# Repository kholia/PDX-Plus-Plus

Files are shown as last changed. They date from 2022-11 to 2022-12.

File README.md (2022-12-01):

#### PDX++ (PDX Plus Plus)

A port of https://github.com/WB2CBA/ADX/ to Raspberry Pi Pico with a couple of
enhancements.

PDX++ uses CD2003 (an AM receiver chip) for RX. For TX, we rely on the
AFSK-driving-Si5351 technique. PDX++ uses the common 3 x BS170 Class-E
amplifier design.

Bands covered: 80-meter to 10-meter.

Note: This repository contains the complete source-code for PDX++ (including
KiCad design files).

Update (17-November-2021): PCB V0.01 was sucessfully validated and is on air!

First QSO from PDX++:

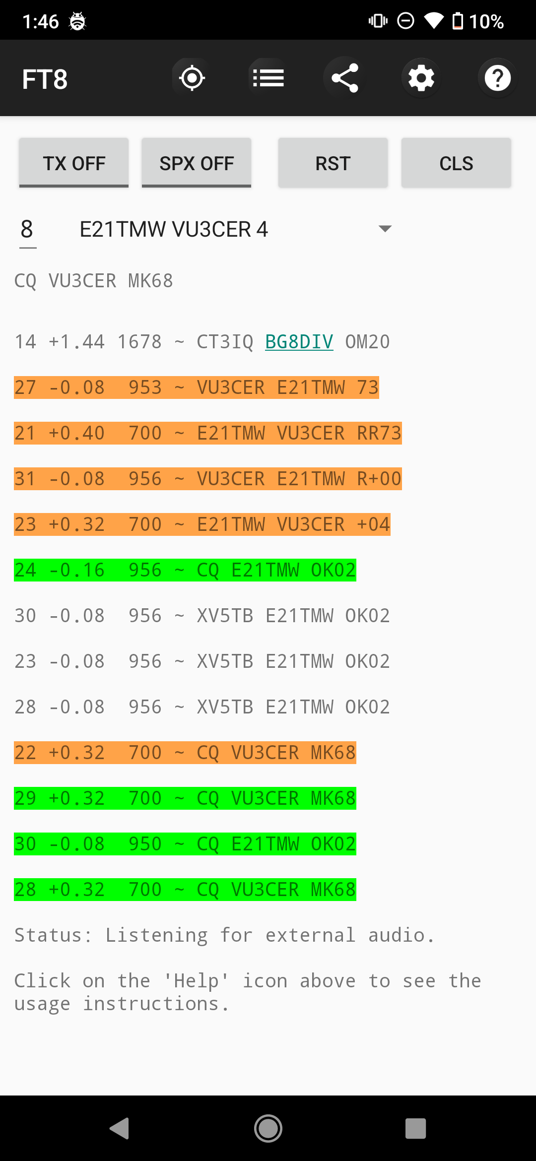
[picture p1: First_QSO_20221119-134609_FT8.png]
First QSO from PDX++ V0.01


QSOs from PDX++:

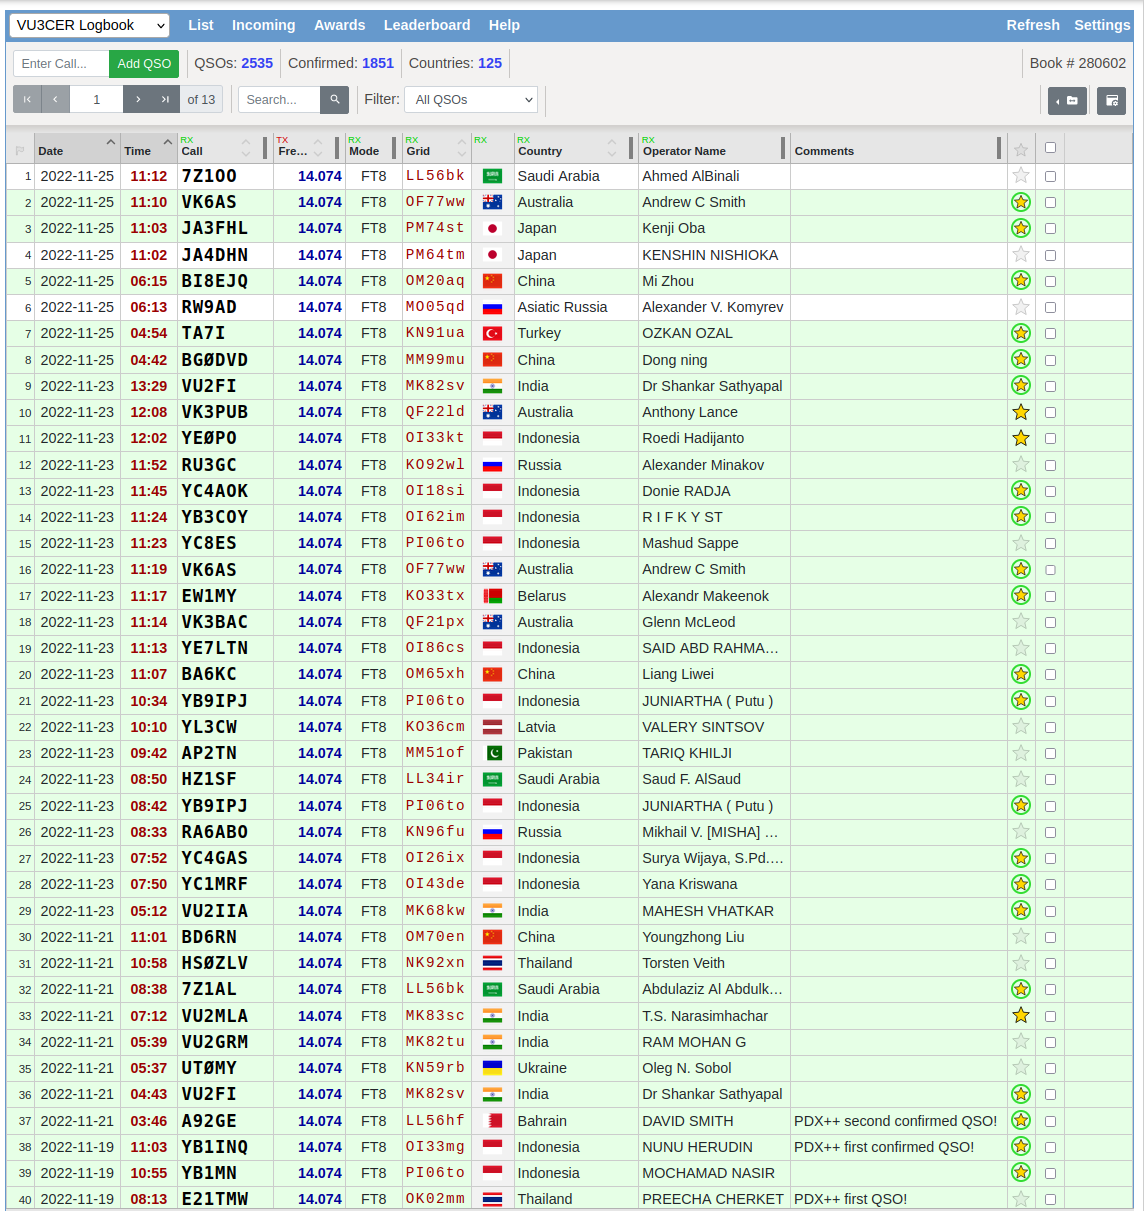
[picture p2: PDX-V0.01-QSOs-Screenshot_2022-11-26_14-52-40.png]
QSOs from PDX++ V0.01


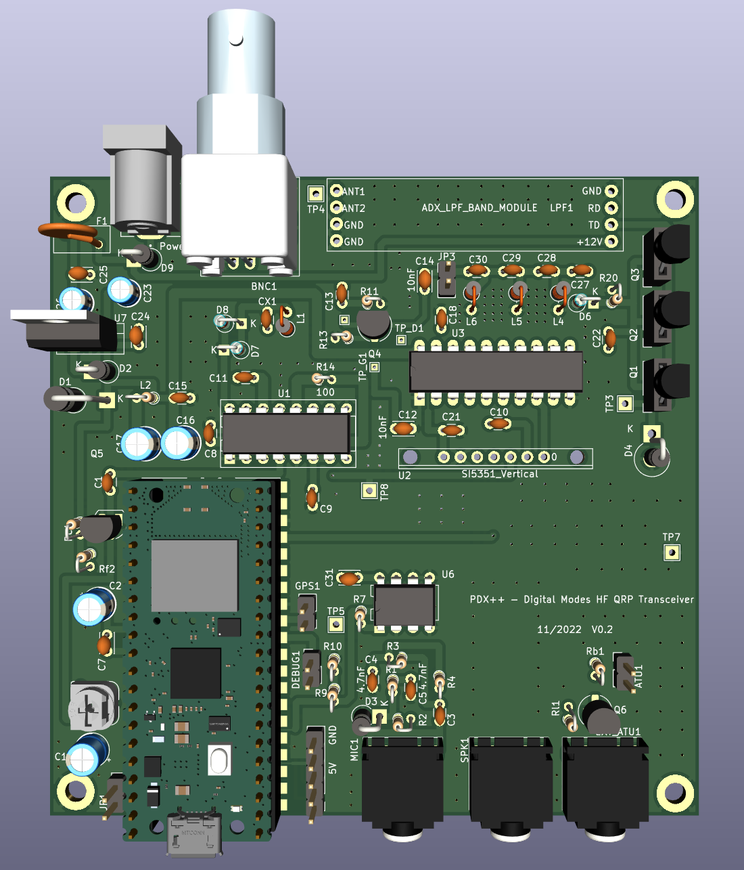
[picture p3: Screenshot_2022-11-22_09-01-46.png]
PCB Render


Note: This project was built using the following:

- KiCad 6.0.x

- https://github.com/earlephilhower/arduino-pico (v2.6.3)

Cost to build: < 1600 INR (around ~20 USD). Including all connectors + LPF.

RX power consumption is 45mA @ 12.0 volts (around 0.56 watt).

#### Schematic

See [the PDX++ schematic](./PDX++.pdf).

#### Build Tips

For the `PCB V0.01` board, build and test the TX section first.

#### Features

- Easy inbuilt and self-sufficient Si5351 calibration

- Inbuilt BCI (broadcast interference) filter

- New AFSK circuit using a LM393 comparator

- Full CAT support (which avoids VOX mode which can trigger false TX under many
  conditions)

- [Optional] Native FT8 decoding on the Pico (via AA1GD)

  - Use https://github.com/kholia/pico_ft8_xcvr firmware

- [Optional] Native spotting (reporting to PSKReporter.info) when using Pico W

  - https://github.com/kholia/SunshineFT8/

#### BOM Sources

International users can buy from Mouser and DigiKey.

Here are some local BOM sources I use:

- https://inkocean.in/ - CD2003 (Chinese clone which is known to work fine)

- https://rarecomponents.com/store/1002 - NXP 1N4148

- https://projectpoint.in/ - CDIL 7805, PJ307 Stereo Socket, winding wire, high quality passives

- https://www.evelta.com/l7805-positive-voltage-regulator-1-5a-5v/ (alternate)

- https://robu.in/product/si5351a-i2c-8-khz-160-mhz-clock-generator-breakout-board-module/

- https://robu.in/product/raspberry-pi-pico/

- https://www.semikart.com/ - has everything we need and more

#### Credits

- https://github.com/WB2CBA/ADX/

- https://github.com/lu7did/ADX-rp2040

- https://github.com/lu7did (ZCD code, freqPIO code)

- https://github.com/aa1gd/pico_ft8_xcvr (AA1GD, for native FT8 decoding)

- https://www.qrz.com/DB/VU2BGS (layout and general help)

#### References

- https://f5npv.wordpress.com/homebrew-ft8qrp-afp-fsk-trx/

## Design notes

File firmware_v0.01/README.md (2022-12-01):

This is the firmware for the `V0.01` PCBs.

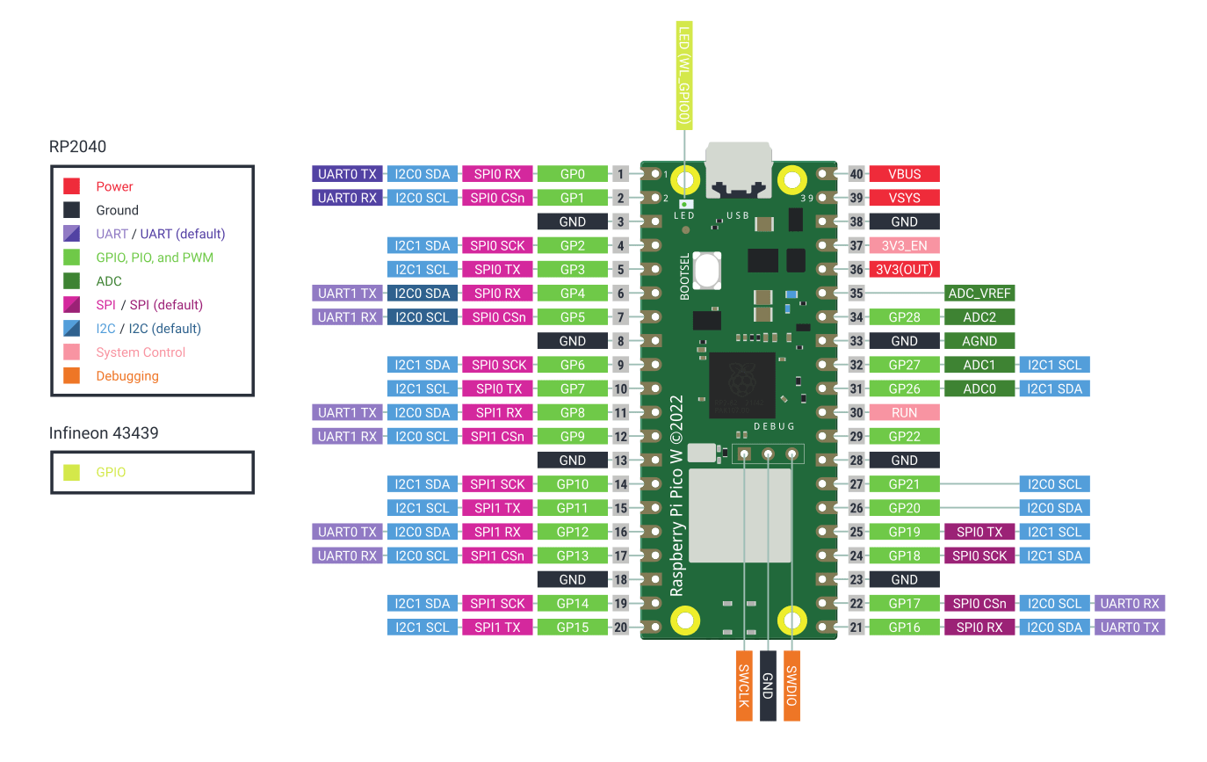
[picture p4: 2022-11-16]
Raspberry-Pi-Pico-W-pinout.png

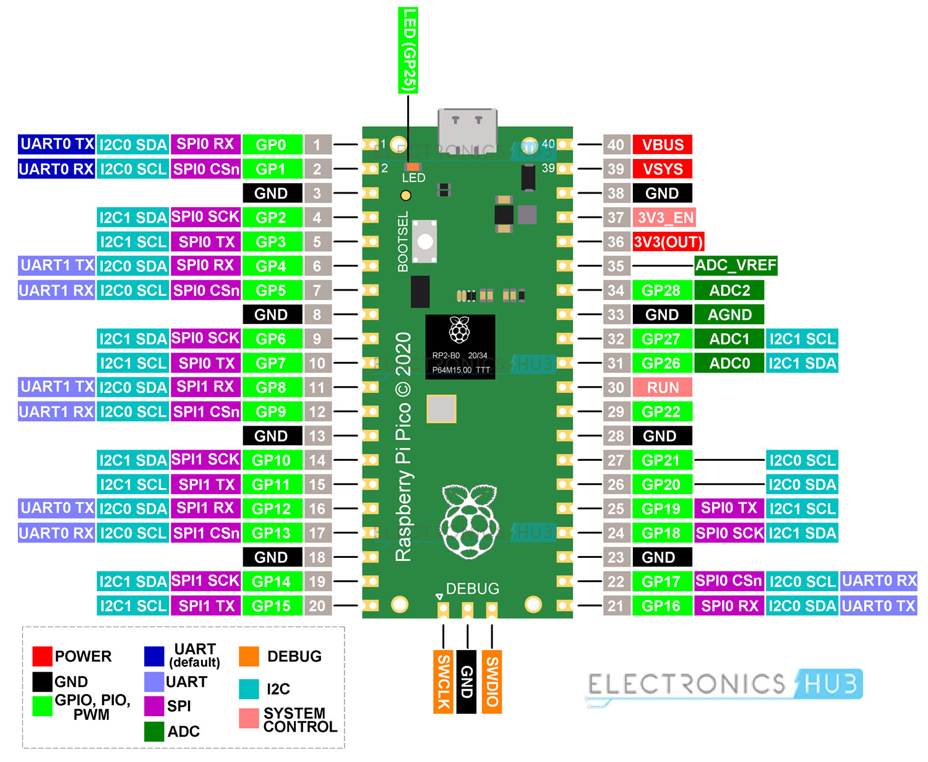
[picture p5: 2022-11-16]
Raspberry-Pi-Pico-Pinout.jpg

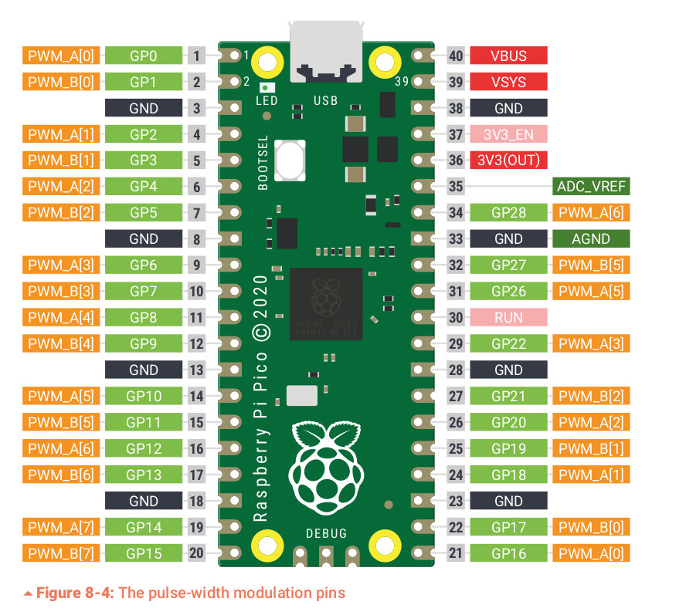
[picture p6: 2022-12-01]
Pico-PWM-Pinout.png

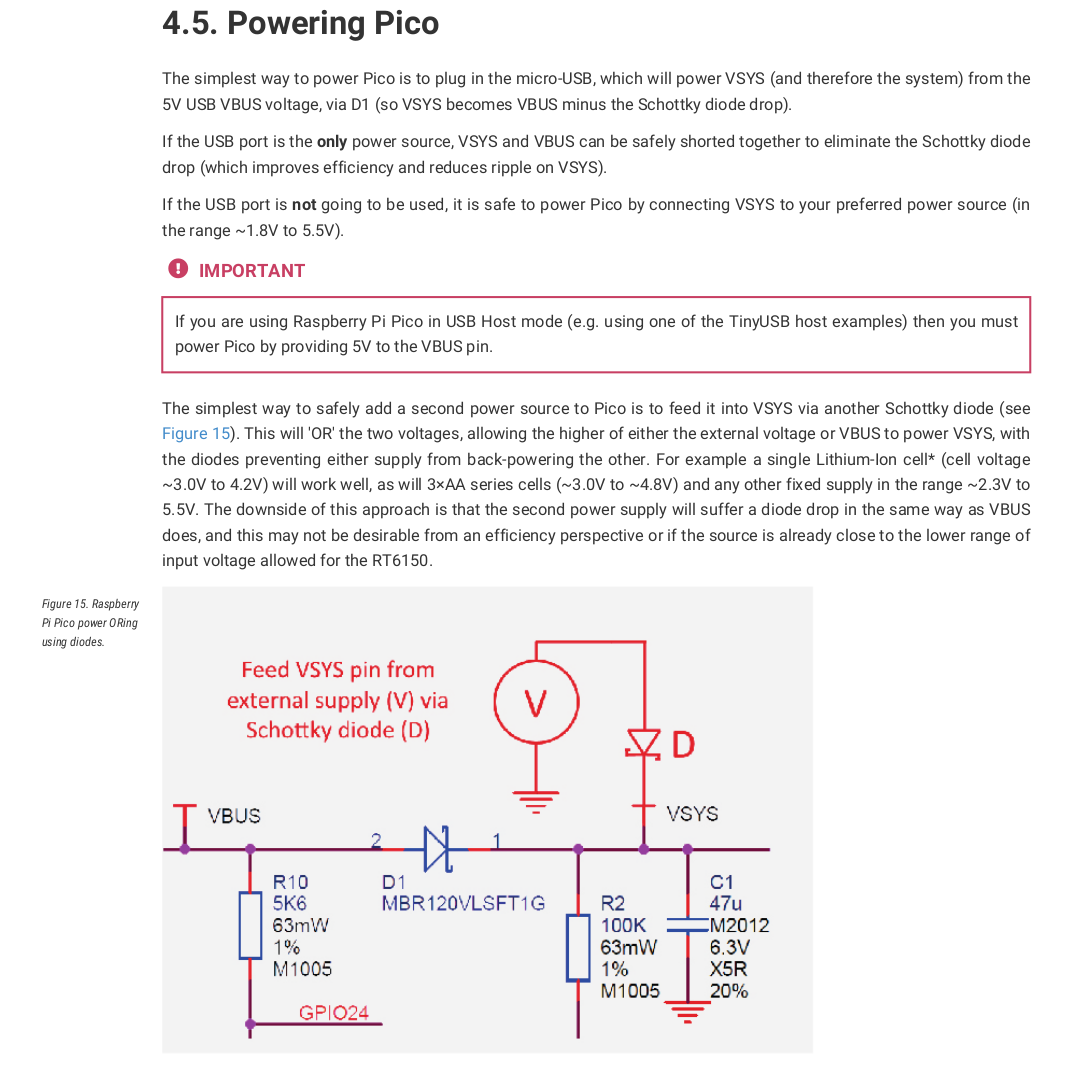
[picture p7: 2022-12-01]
Screenshot_2022-11-25_11-38-42.png

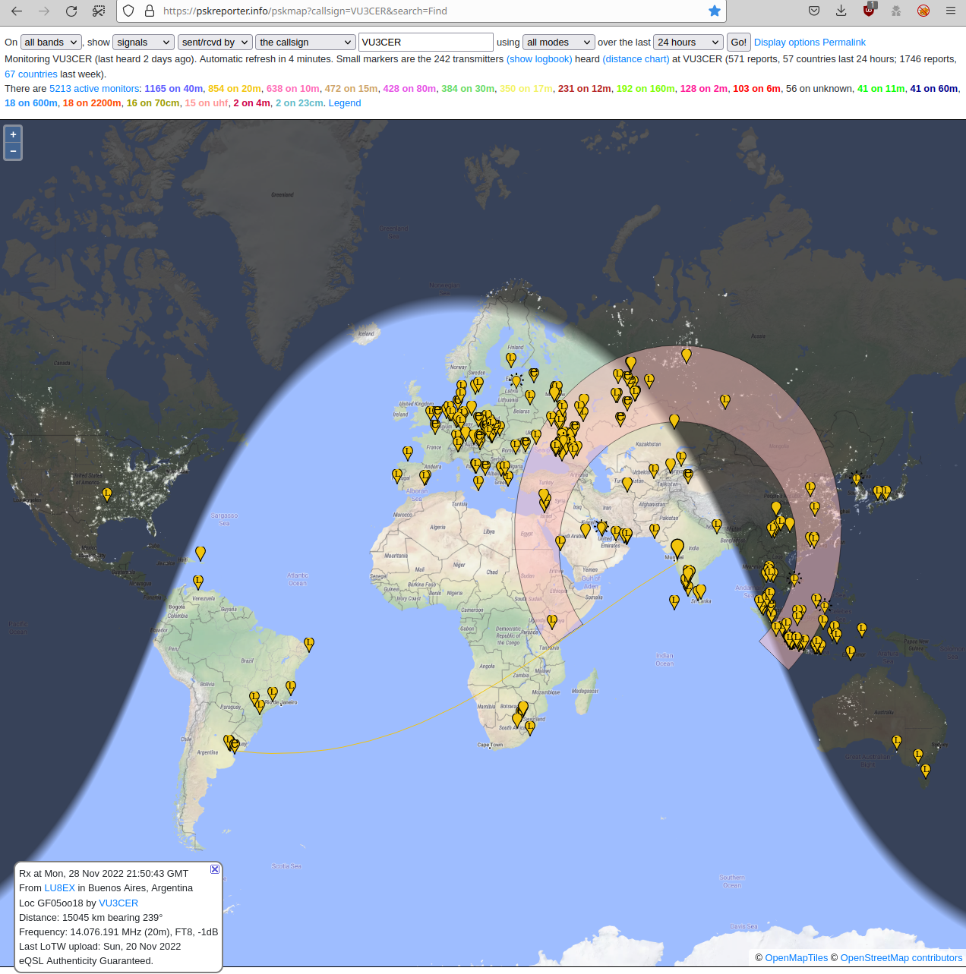
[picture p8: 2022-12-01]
screenshots/Screenshot_2022-11-29_16-37-07.png

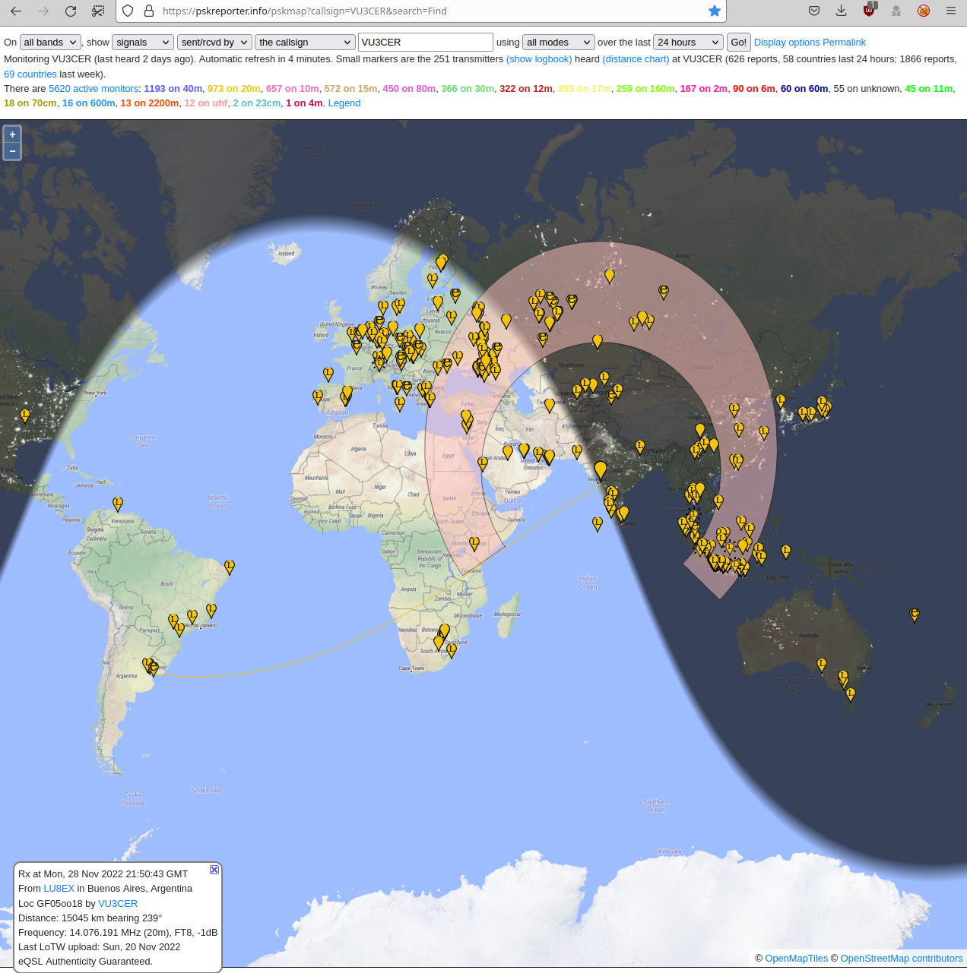
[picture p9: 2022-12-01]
screenshots/Screenshot_2022-11-29_17-54-42.png

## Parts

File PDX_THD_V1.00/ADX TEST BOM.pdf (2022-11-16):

Comment | Designator
SSD1306 | Brd1
100uF/16V | C1,C23,C27
470nF | C12
620pF | C13
Cx | C14
10nF | C19,C20
10uF/16V | C4,C22,C26,C30
10nF | C6,C7
100nF | C2,C3,C5,C8,C9,C10,C11,C15,C16,C17,C18,C21,C24,C25,C28,C29
TX | D1
1N5817 | D10
1N4148 | D2
1N4148 | D4,D5
FT8 | D6
FT4 | D7
JS8 | D8
WSPR | D9
MountingHole_Pad | H1,H2,H3,H4
SMA | J1
BNC | J1A1
PJ‐102A | J2
USB_B | J3
100uH | L1
1uH | L3
100uH | L4,L5,L6
BS170 | Q1,Q2,Q3
BS170 | Q4
1M | R1
2.7k | R10
100 | R11
4.7k | R2
10k | R3,R4,R5,R6
1k | R9,R12,R13,R14,R15,R16
10k | RV1
UP | SW1
BAND | SW2
PA DC | SW3
CLK0 | TP1
CLK1 | TP2
TestPoint | TP3,TP4
| TP5,TP6
GND | TP7
CAL | TP8
CM108AH_Sound_Card | U1
SI535X_Module | U2
74ACT244 | U3
uSDX_LPF_BAND_MODULE | U4
CD2003GB_GP | U5
Arduino_Nano_Socket | XA1

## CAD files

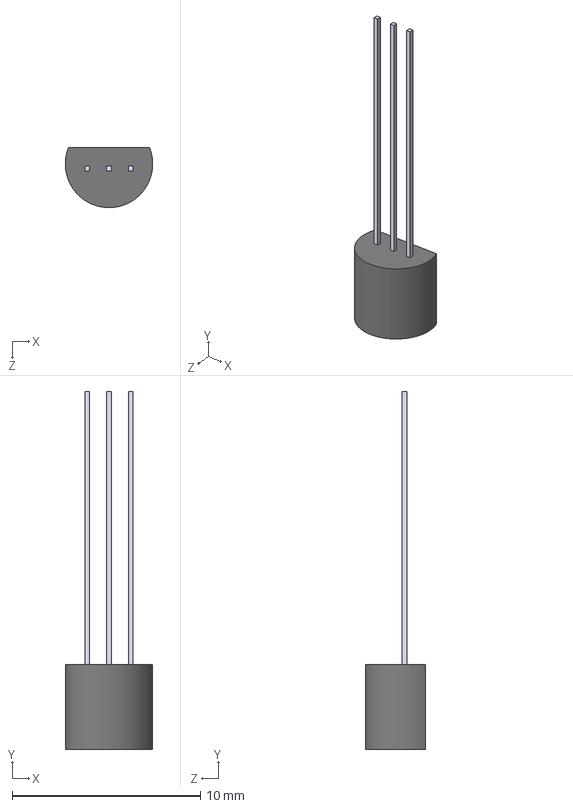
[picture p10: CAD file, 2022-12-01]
models/Transistor_TO-92_Type.STEP
4.64 x 19.0 x 3.20 mm

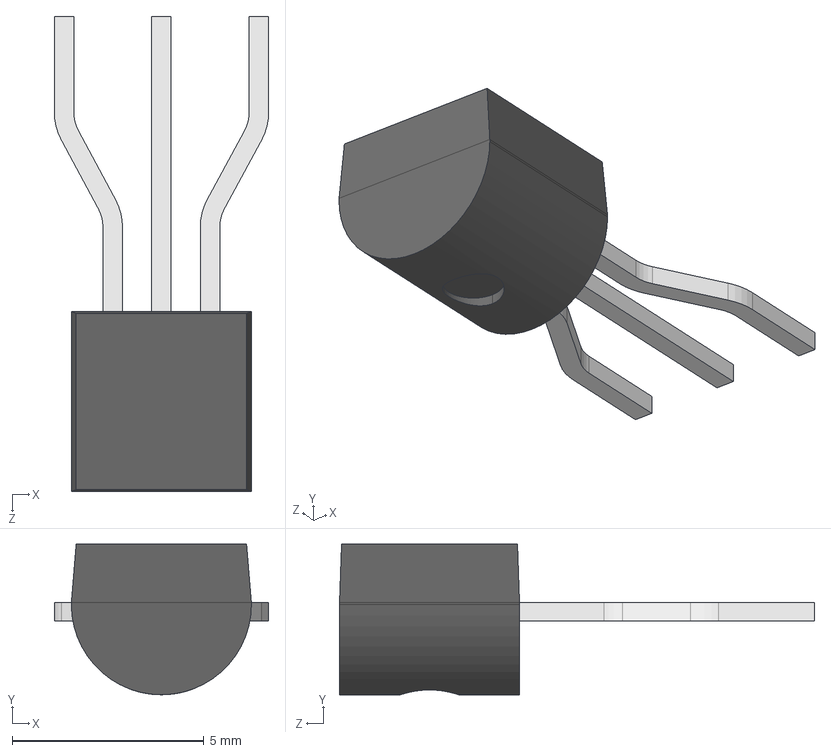
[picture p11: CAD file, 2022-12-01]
models/User Library-TO-92-2_54-line.STEP
5.60 x 3.93 x 12.4 mm
User Library-TO-92 Version2_TO-92 Part1
User Library-TO-92 Version2_TO-92 Part3
User Library-TO-92 Version2_TO-92 Part4
User Library-TO-92 Version2_TO-92 Part5

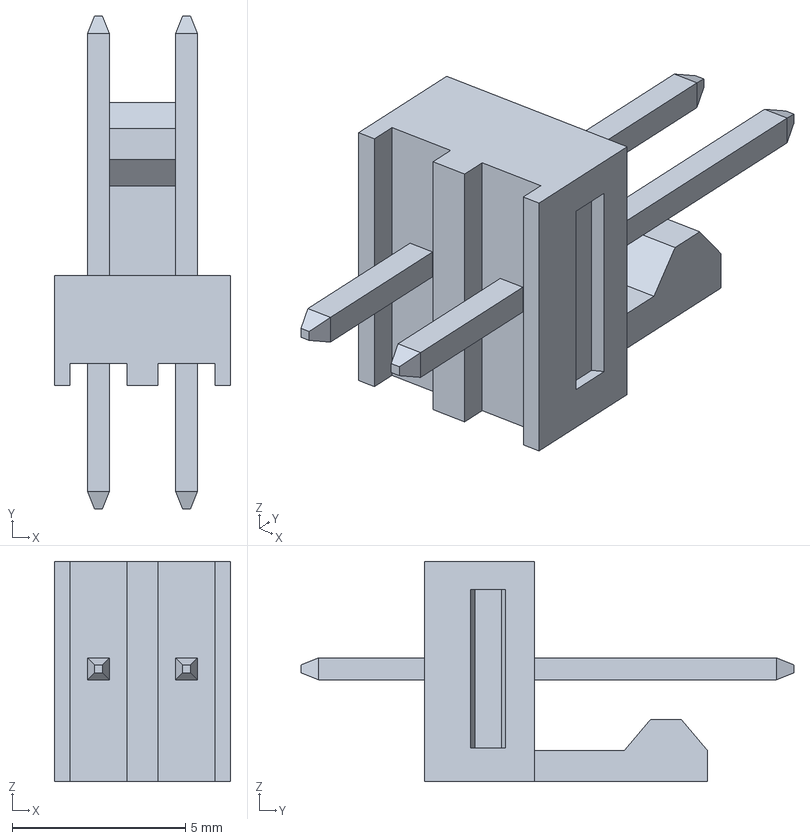
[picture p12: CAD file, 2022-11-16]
models/22-23-2021.stp
5.08 x 14.2 x 6.35 mm

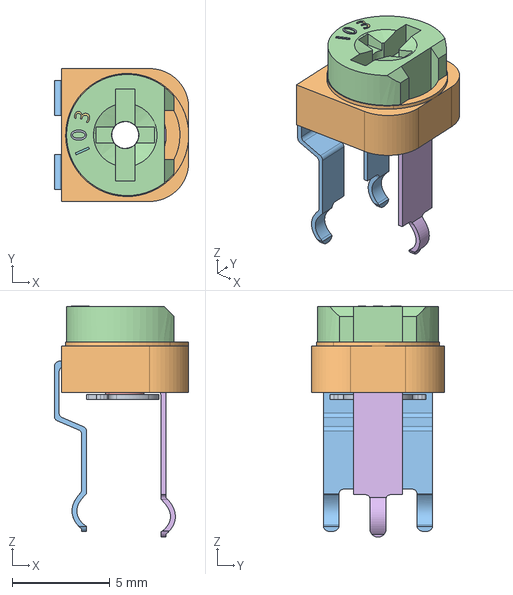
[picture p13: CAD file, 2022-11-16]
models/Poti_10kohm.stp
6.88 x 6.80 x 11.8 mm

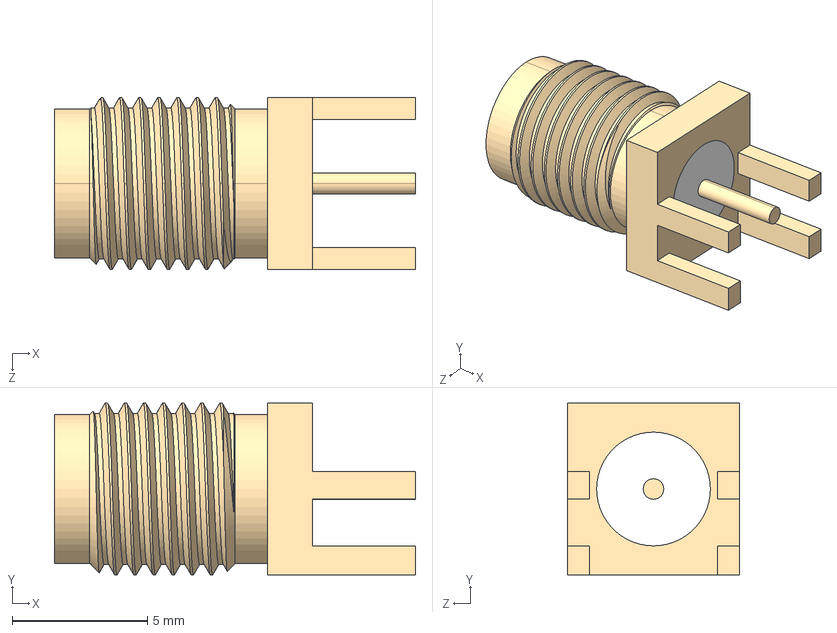
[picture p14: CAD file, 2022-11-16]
models/CON-SMA-EDGE-S--3DModel-STEP-56544.STEP
13.3 x 6.35 x 6.35 mm

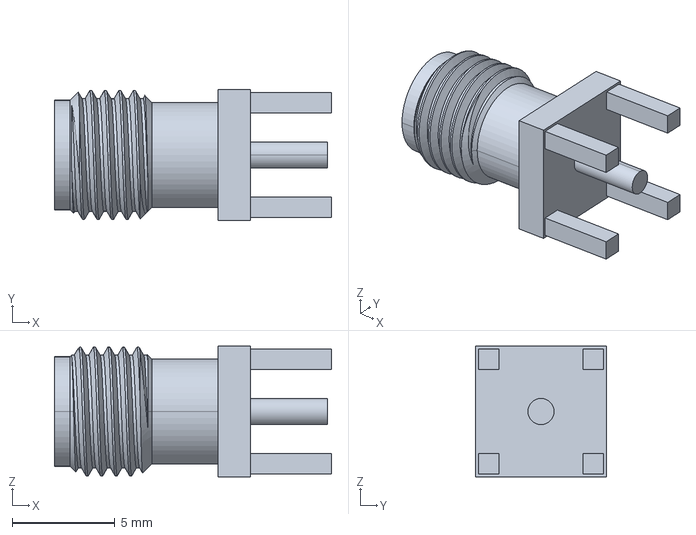
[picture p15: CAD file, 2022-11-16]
models/901-144.stp
13.5 x 6.35 x 6.35 mm

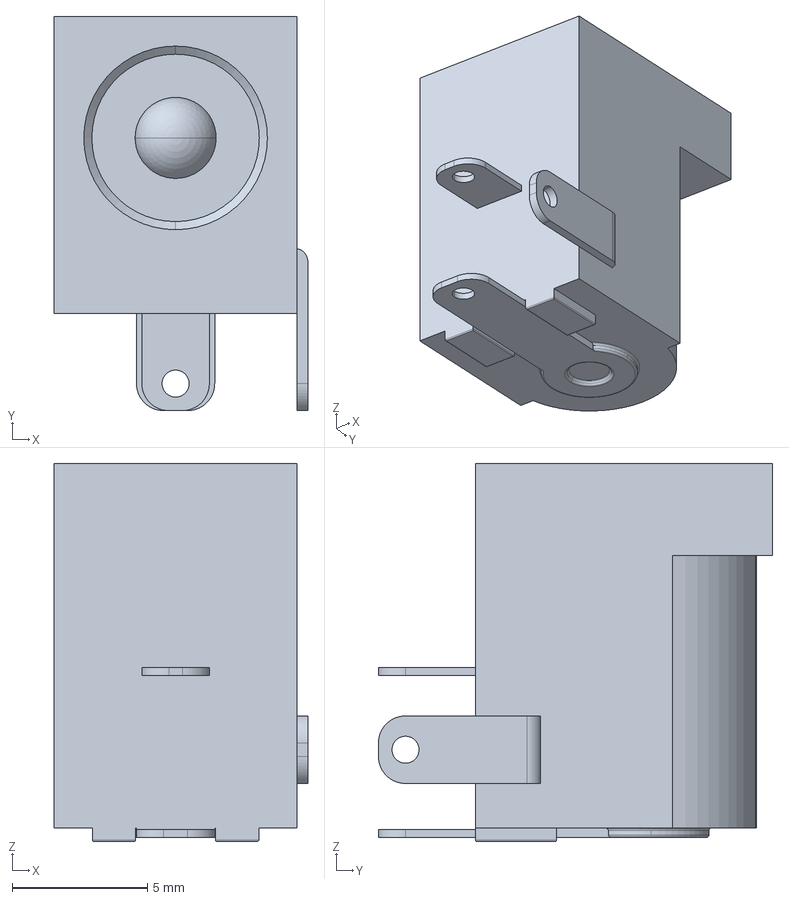
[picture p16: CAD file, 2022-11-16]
models/DC-005-5A-2.0.step
9.40 x 14.6 x 14.0 mm

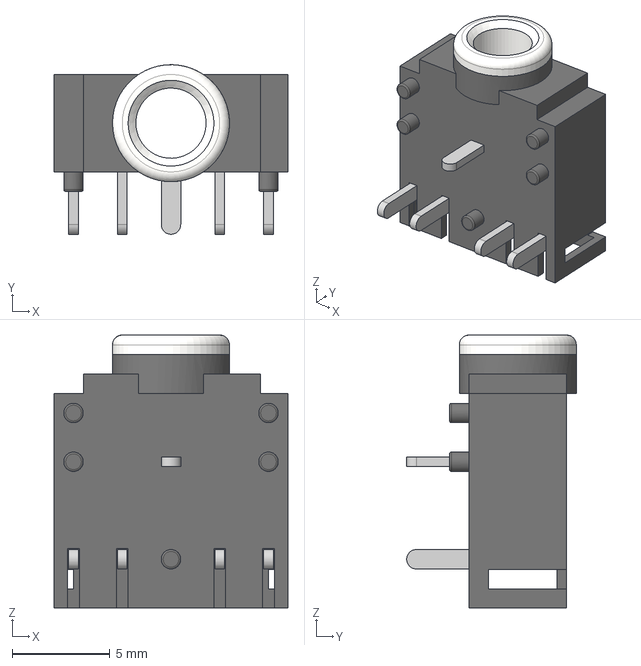
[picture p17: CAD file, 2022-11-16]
models/pj-307.step
12.0 x 8.70 x 14.0 mm

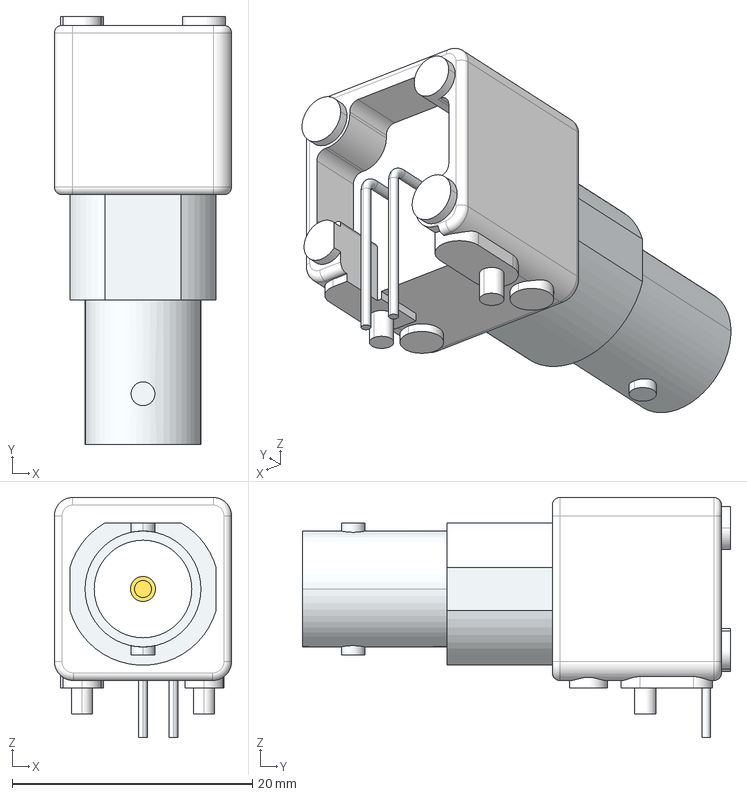
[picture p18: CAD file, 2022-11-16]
models/1564889-62.stp
14.8 x 35.7 x 20.0 mm

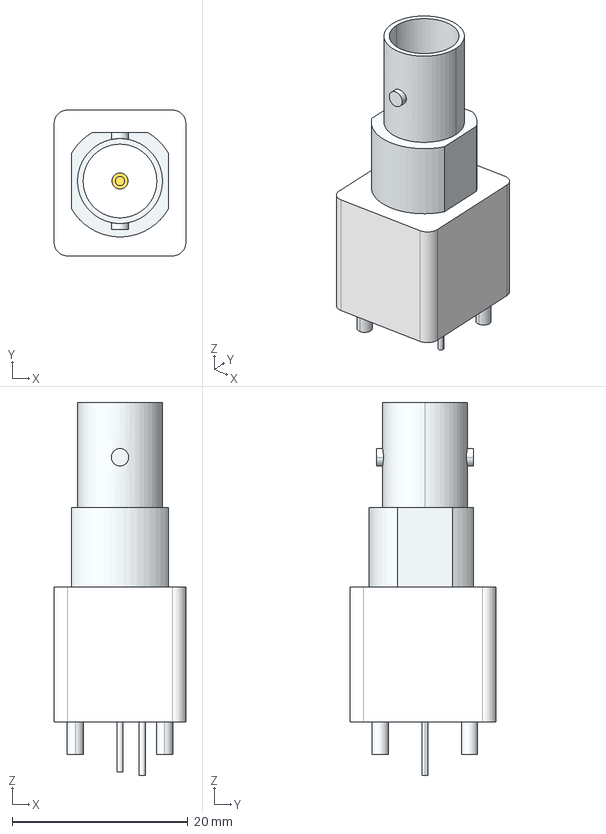
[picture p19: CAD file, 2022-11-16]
models/1566143-62.stp
15.0 x 16.6 x 42.4 mm

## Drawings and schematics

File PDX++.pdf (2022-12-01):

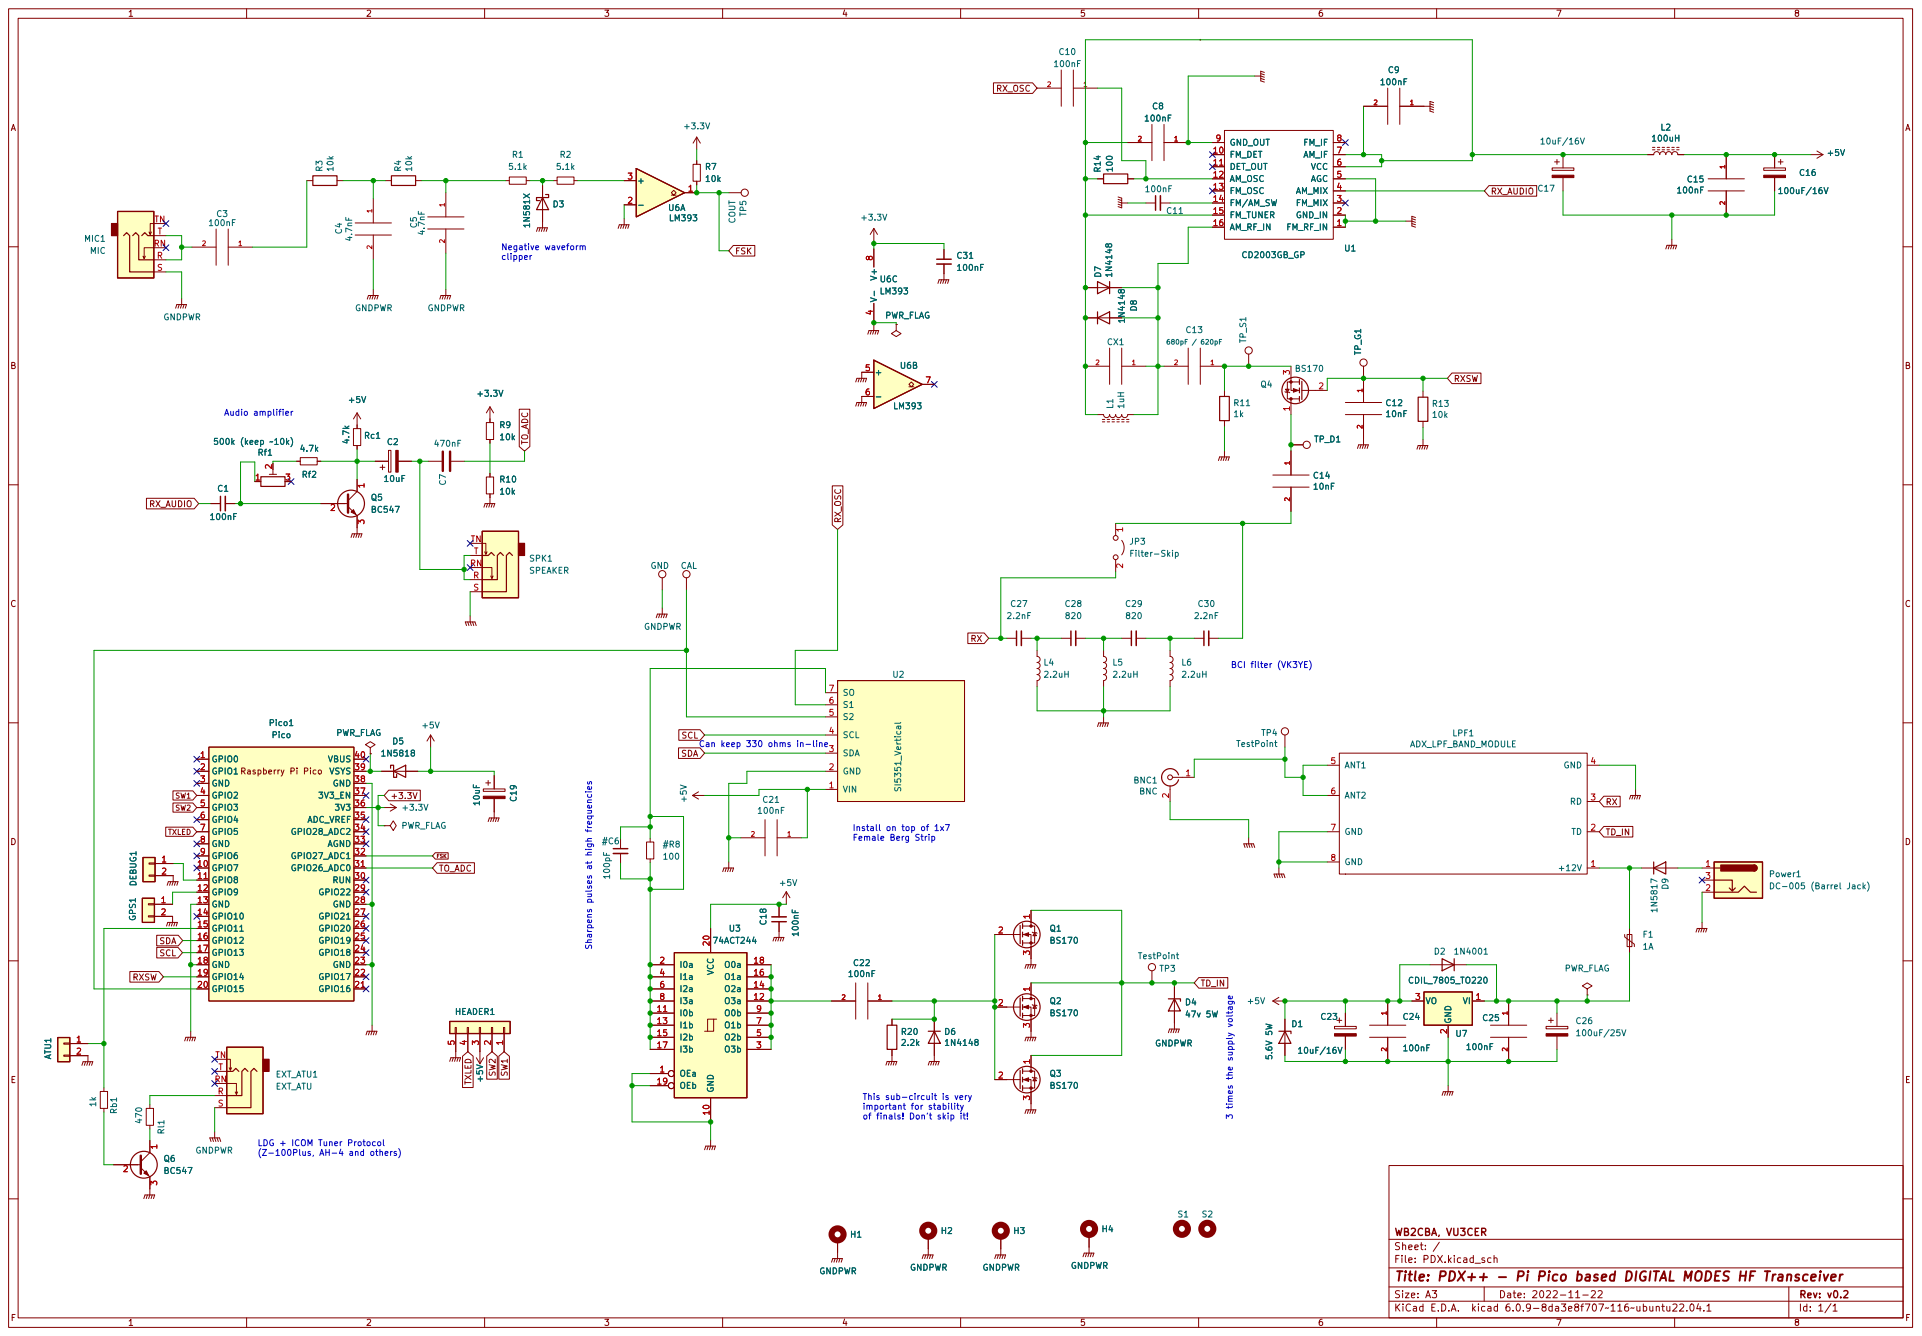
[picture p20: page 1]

3 Pico1 Pico GPIO0 1 GPIO7 10 GPIO8 11 GPIO9 12 GND 13 GPIO10 14 GPIO11 15 GPIO12 16 GPIO13 17 GND 18 GPIO14 19 GPIO1 2 GPIO15 20 GPIO16 21 GPIO17 22 GND 23 GPIO18 24 GPIO19 25 GPIO20 26 GPIO21 27 GND 28 GPIO22 29 GND 3 RUN 30 GPIO26_ADC0 31 GPIO27_ADC1 32 AGND 33 GPIO28_ADC2 34 ADC_VREF 35

Can keep 330 ohms in-line
SDA

Install on top of 1x7
Female Berg Strip

This sub-circuit is very
important for stability

of finals! Don't skip it! LDG + ICOM Tuner Protocol (Z-100Plus, AH-4 and others)

Id: 1/1 Title: PDX++ - Pi Pico based DIGITAL MODES HF Transceiver

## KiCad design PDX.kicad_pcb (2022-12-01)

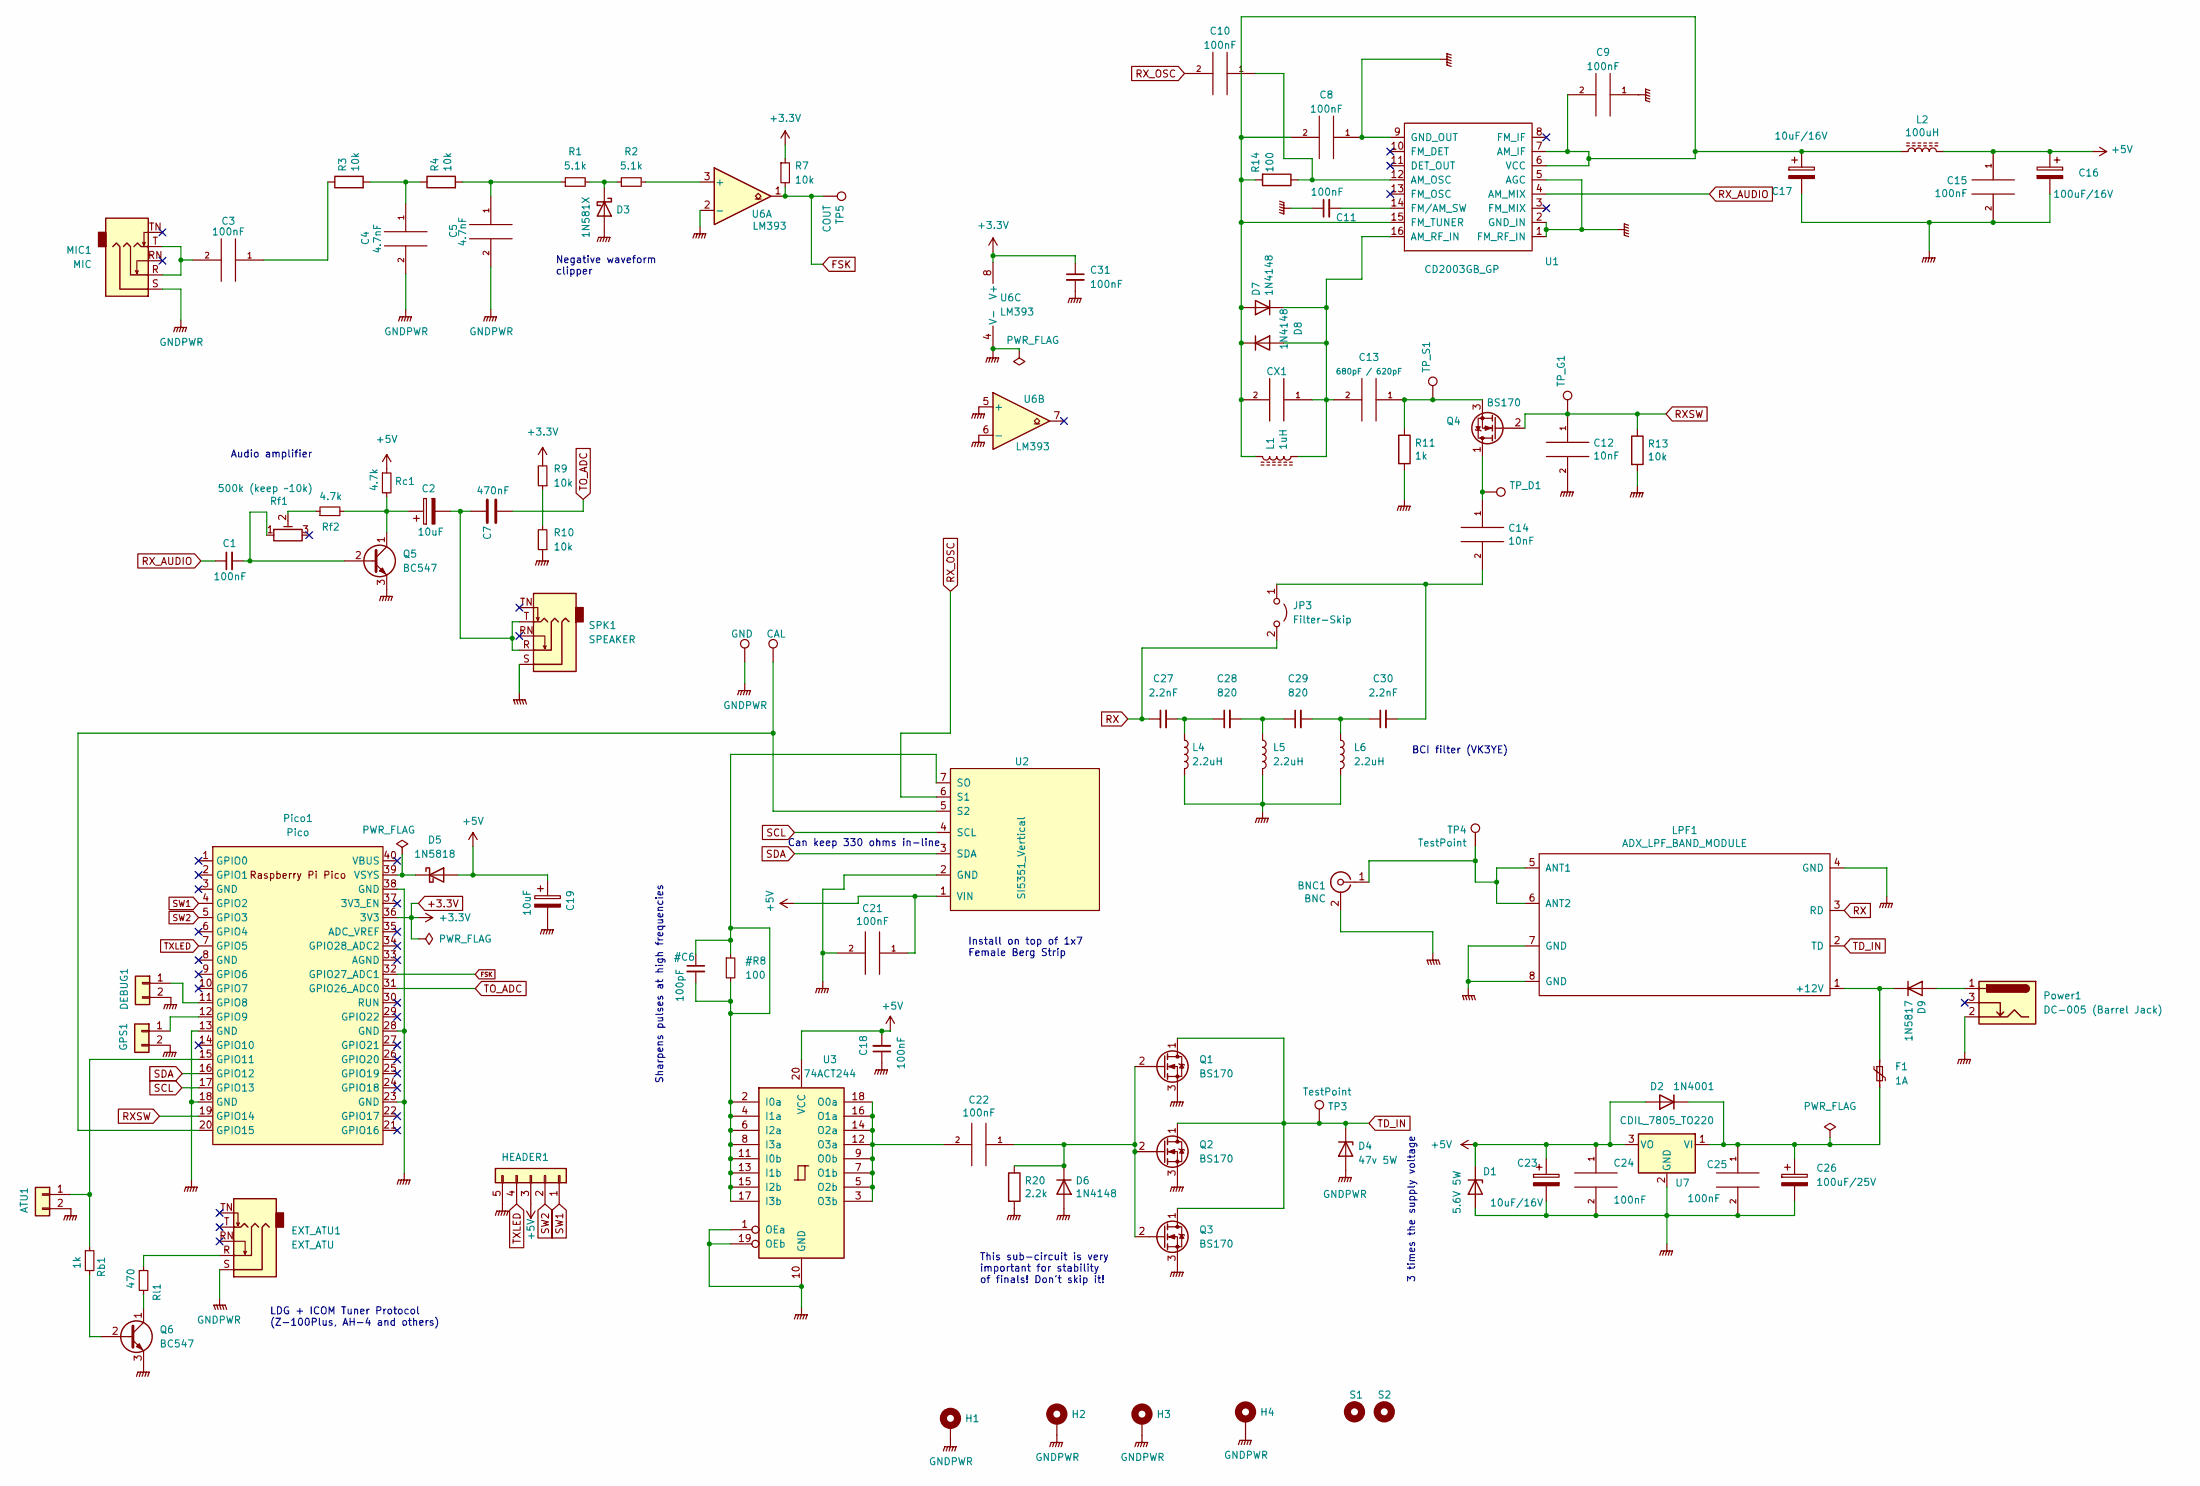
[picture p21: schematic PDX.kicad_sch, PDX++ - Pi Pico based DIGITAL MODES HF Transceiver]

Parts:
ATU1: Conn_01x02; PinHeader_1x02_P2.54mm_Vertical
BNC1: BNC; BNC_Amphenol_B6252HB-NPP3G-50_Horizontal
C1, C3, C8, C9, C10, C11, C15, C18, C21, C22: 100nF; C_Disc_D3.0mm_W1.6mm_P2.50mm
C2, C19: 10uF; CP_Radial_D5.0mm_P2.50mm
C4, C5: 4.7nF; C_Disc_D3.0mm_W1.6mm_P2.50mm
C7: 470nF; C_Disc_D3.0mm_W2.0mm_P2.50mm
C12, C14: 10nF; C_Disc_D3.0mm_W2.0mm_P2.50mm
C13: 680pF / 620pF; C_Disc_D3.0mm_W1.6mm_P2.50mm
C16: 100uF/16V; CP_Radial_D5.0mm_P2.50mm
C17: 10uF/16V; CP_Radial_D5.0mm_P2.50mm
C23: 10uF/16V; CP_Radial_D4.0mm_P2.00mm
C24, C25, C31: 100nF; C_Disc_D3.0mm_W2.0mm_P2.50mm
C26: 100uF/25V; CP_Radial_D4.0mm_P2.00mm
C27, C30: 2.2nF; C_Disc_D3.0mm_W1.6mm_P2.50mm
C28, C29: 820; C_Disc_D3.0mm_W1.6mm_P2.50mm
CX1: C_Disc_D3.0mm_W1.6mm_P2.50mm
D1: 5.6V 5W; D_DO-15_P5.08mm_Vertical_KathodeUp
D2: 1N4001; D_DO-41_SOD81_P2.54mm_Vertical_KathodeUp
D3: 1N581X; D_DO-41_SOD81_P2.54mm_Vertical_KathodeUp
D4: 47v 5W; D_DO-201_P3.81mm_Vertical_KathodeUp
D5: 1N5818; D_DO-41_SOD81_P2.54mm_Vertical_KathodeUp
D6, D7, D8: 1N4148; D_DO-35_SOD27_P2.54mm_Vertical_KathodeUp
D9: 1N5817; D_DO-41_SOD81_P2.54mm_Vertical_KathodeUp
DEBUG1: Conn_01x02; PinHeader_1x02_P2.54mm_Vertical
EXT_ATU1: EXT_ATU; PJ-307_Modded
F1: 1A; Fuse_BelFuse_0ZRE0005FF_L8.3mm_W3.8mm
GPS1: Conn_01x02; PinHeader_1x02_P2.54mm_Vertical
H1, H2, H3, H4: MountingHole_Pad; MountingHole_3.2mm_M3_ISO7380_Pad
HEADER1: Conn_01x05; PinHeader_1x05_P2.54mm_Vertical
JP3: Filter-Skip; PinHeader_1x02_P2.54mm_Vertical
L1: 1uH; L_Axial_L5.3mm_D2.2mm_P2.54mm_Vertical_Vishay_IM-1
L2: 100uH; R_Axial_DIN0204_L3.6mm_D1.6mm_P2.54mm_Vertical
L4, L5, L6: 2.2uH; L_Axial_L5.3mm_D2.2mm_P2.54mm_Vertical_Vishay_IM-1
LPF1: ADX_LPF_BAND_MODULE; uSDX_LPF_Band_Module
MIC1: MIC; PJ-307_Modded
Pico1: Pico; RPi_Pico_SMD_TH
Power1: DC-005 (Barrel Jack); XKB_DC-005-5A-2.0
Q1, Q2, Q3: BS170; PinSocket_1x03_P2.54mm_Vertical
Q4: BS170; TO-92_HandSolder
Q5, Q6: BC547; TO-92_HandSolder
R1, R2: 5.1k; R_Axial_DIN0204_L3.6mm_D1.6mm_P1.90mm_Vertical
R3, R4, R7, R9, R10, R13: 10k; R_Axial_DIN0204_L3.6mm_D1.6mm_P1.90mm_Vertical
R11: 1k; R_Axial_DIN0204_L3.6mm_D1.6mm_P1.90mm_Vertical
R14: 100; R_Axial_DIN0204_L3.6mm_D1.6mm_P1.90mm_Vertical
R20: 2.2k; R_Axial_DIN0204_L3.6mm_D1.6mm_P1.90mm_Vertical
Rb1: 1k; R_Axial_DIN0204_L3.6mm_D1.6mm_P1.90mm_Vertical
Rc1: 4.7k; R_Axial_DIN0204_L3.6mm_D1.6mm_P1.90mm_Vertical
Rf1: 500k (keep ~10k); Potentiometer_Runtron_RM-065_Vertical
Rf2: 4.7k; R_Axial_DIN0204_L3.6mm_D1.6mm_P1.90mm_Vertical
Rl1: 470; R_Axial_DIN0204_L3.6mm_D1.6mm_P1.90mm_Vertical
S1, S2: MountingHole; MountingHole_2.2mm_M2
SPK1: SPEAKER; PJ-307_Modded
TP3, TP4: TestPoint; TestPoint_THTPad_2.0x2.0mm_Drill1.0mm
TP5: COUT; TestPoint_THTPad_2.0x2.0mm_Drill1.0mm
TP7: GND; TestPoint_THTPad_2.0x2.0mm_Drill1.0mm
TP8: CAL; TestPoint_THTPad_2.0x2.0mm_Drill1.0mm
TP_D1: TestPoint_THTPad_1.0x1.0mm_Drill0.5mm
TP_G1: TestPoint_THTPad_1.0x1.0mm_Drill0.5mm
TP_S1: TestPoint_THTPad_1.0x1.0mm_Drill0.5mm
U1: CD2003GB_GP; DIP-16_W7.62mm_Socket
U2: SI5351_Vertical; SI5351 Module_Vertical
U3: 74ACT244; DIP-20_W7.62mm_LongPads
U6: LM393; DIP-8_W7.62mm
U7: CDIL_7805_TO220; TO-220-3_Vertical

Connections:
+3.3V: C31.1, Pico1.36 (3V3), R7.1, R9.2, U6.8 (V+)
+5V: C15.1, C16.1, C18.2, C19.1, C21.1, C23.1, C24.1, D1.1 (K), D2.2 (A), D5.2 (A), HEADER1.3, L2.1, Rc1.1, U2.1 (VIN), U3.20 (VCC), U7.3 (VO)
FSK: Pico1.32 (GPIO27_ADC1), R7.2, TP5.1, U6.1
GNDPWR: ATU1.2, BNC1.2 (Ext), C4.2, C5.2, C8.1, C9.1, C11.1, C12.2, C15.2, C16.2, C17.2, C18.1, C19.2, C21.2, C23.2, C24.2, C25.2, C26.2, C31.2, D1.2 (A), D3.2 (A), D4.2 (A), D6.2 (A), DEBUG1.2, EXT_ATU1.S, GPS1.2, H1.1, H2.1, H3.1, H4.1, HEADER1.5, L4.2, L5.2, L6.2, LPF1.4 (GND), LPF1.7 (GND), LPF1.8 (GND), MIC1.S, Pico1.13 (GND), Pico1.18 (GND), Pico1.23 (GND), Pico1.28 (GND), Pico1.38 (GND), Power1.2, Q1.3 (S), Q2.3 (S), Q3.3 (S), Q5.3 (E), Q6.3 (E), R10.1, R11.2, R13.2, R20.2, SPK1.S, TP7.1, U1.1 (FM_RF_IN), U1.2 (GND_IN), U1.5 (AGC), U1.9 (GND_OUT), U2.2 (GND), U3.1 (OEa), U3.10 (GND), U3.19 (OEb), U6.2 (-), U6.4 (V-), U6.5 (+), U6.6 (-), U7.2 (GND)
unnamed: ATU1.1, Pico1.15 (GPIO11), Rb1.1
unnamed: BNC1.1 (In), LPF1.5 (ANT1), LPF1.6 (ANT2), TP4.1
unnamed: C1.2, Q5.2 (B), Rf1.1
unnamed: C2.1, Q5.1 (C), Rc1.2, Rf2.2
unnamed: C2.2, C7.2, SPK1.R, SPK1.T
unnamed: C3.1, R3.1
unnamed: C3.2, MIC1.R, MIC1.T
unnamed: C4.1, R3.2, R4.1
unnamed: C5.1, R1.1, R4.2
unnamed: C10.1, R14.1, U1.12 (AM_OSC)
unnamed: C11.2, U1.14 (FM/AM_SW)
unnamed: C13.1, Q4.3 (S), R11.1, TP_S1.1
unnamed: C13.2, CX1.1, D7.1 (K), D8.2 (A), L1.1, U1.16 (AM_RF_IN)
unnamed: C14.1, Q4.1 (D), TP_D1.1
unnamed: C14.2, C30.2, JP3.1 (A)
unnamed: C8.2, C9.2, C17.1, CX1.2, D7.2 (A), D8.1 (K), L1.2, L2.2, R14.2, U1.6 (VCC), U1.7 (AM_IF), U1.15 (FM_TUNER)
unnamed: C22.1, D6.1 (K), Q1.2 (G), Q2.2 (G), Q3.2 (G), R20.1
unnamed: C22.2, U3.3 (O3b), U3.5 (O2b), U3.7 (O1b), U3.9 (O0b), U3.12 (O3a), U3.14 (O2a), U3.16 (O1a), U3.18 (O0a)
unnamed: C25.1, C26.1, D2.1 (K), F1.2, U7.1 (VI)
unnamed: C27.2, C28.1, L4.1
unnamed: C28.2, C29.1, L5.1
unnamed: C29.2, C30.1, L6.1
unnamed: D3.1 (K), R1.2, R2.1
unnamed: D5.1 (K), Pico1.39 (VSYS)
unnamed: D9.1 (K), F1.1, LPF1.1 (+12V)
unnamed: D9.2 (A), Power1.1
unnamed: DEBUG1.1, Pico1.11 (GPIO8)
unnamed: EXT_ATU1.R, Rl1.1
unnamed: GPS1.1, Pico1.12 (GPIO9)
unnamed: Pico1.20 (GPIO15), TP8.1, U2.5 (S2)
unnamed: Q6.1 (C), Rl1.2
unnamed: Q6.2 (B), Rb1.2
unnamed: R2.2, U6.3 (+)
unnamed: R9.1, R10.2
unnamed: Rf1.2, Rf2.1
unnamed: U2.7 (SO), U3.2 (I0a), U3.4 (I1a), U3.6 (I2a), U3.8 (I3a), U3.11 (I0b), U3.13 (I1b), U3.15 (I2b), U3.17 (I3b)
RX: C27.1, JP3.2 (B), LPF1.3 (RD)
RXSW: C12.1, Pico1.19 (GPIO14), Q4.2 (G), R13.1, TP_G1.1
RX_AUDIO: C1.1, U1.4 (AM_MIX)
RX_OSC: C10.2, U2.6 (S1)
SCL: Pico1.17 (GPIO13), U2.4 (SCL)
SDA: Pico1.16 (GPIO12), U2.3 (SDA)
SW1: HEADER1.1, Pico1.4 (GPIO2)
SW2: HEADER1.2, Pico1.5 (GPIO3)
TD_IN: D4.1 (K), LPF1.2 (TD), Q1.1 (D), Q2.1 (D), Q3.1 (D), TP3.1
TO_ADC: C7.1, Pico1.31 (GPIO26_ADC0)
TXLED: HEADER1.4, Pico1.7 (GPIO5)

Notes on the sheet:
Install on top of 1x7 Female Berg Strip
This sub-circuit is very important for stability of finals! Don't skip it!
Audio amplifier
Can keep 330 ohms in-line
Sharpens pulses at high frequencies
Negative waveform clipper
LDG + ICOM Tuner Protocol (Z-100Plus, AH-4 and others)
BCI filter (VK3YE)
3 times the supply voltage

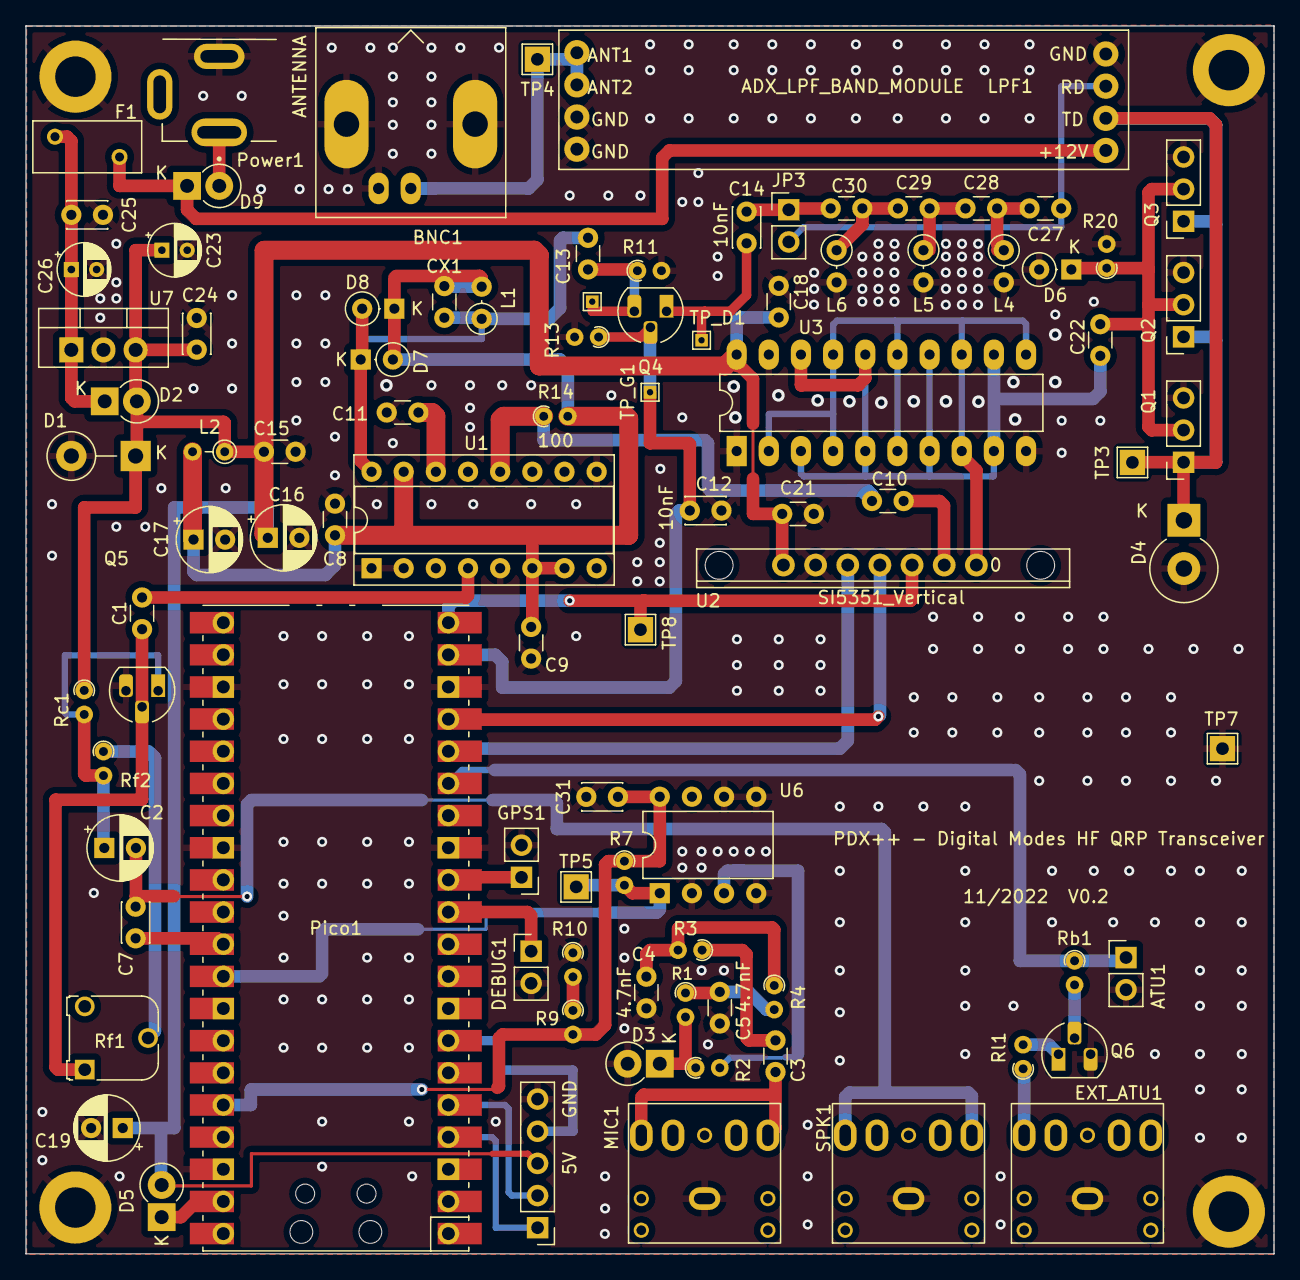
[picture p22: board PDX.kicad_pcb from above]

Board: 2 copper layers, 98.6 x 97.0 mm, 98 parts (0 on the bottom side), 51 nets.

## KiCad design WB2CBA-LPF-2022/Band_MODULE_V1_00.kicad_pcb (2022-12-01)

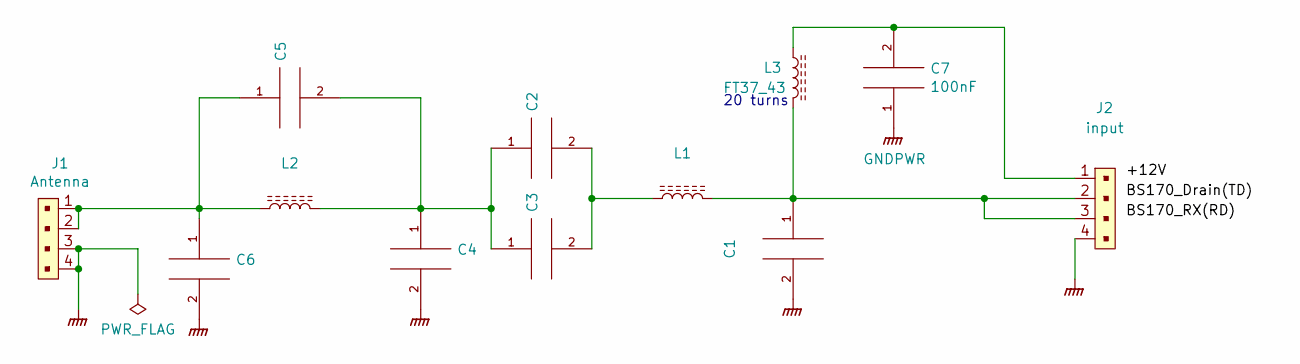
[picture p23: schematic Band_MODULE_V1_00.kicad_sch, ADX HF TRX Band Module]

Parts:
C1, C2, C3, C4, C5, C6: C_Disc_D5.0mm_W2.5mm_P2.50mm
C7: 100nF; C_Disc_D5.0mm_W2.5mm_P2.50mm
J1: Antenna; PinHeader_1x4_P2.54mm_Drill1.02mm; MPN 0022232041; Digi-Key_PN WM4202-ND
J2: input; PinHeader_1x4_P2.54mm_Drill1.02mm; MPN 0022232041; Digi-Key_PN WM4202-ND
L1, L2: L_Toroid_Vertical_L10.0mm_W5.0mm_P5.08mm
L3: FT37_43; L_Toroid_Vertical_L10.0mm_W5.0mm_P5.08mm

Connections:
GNDPWR: C1.2, C4.2, C6.2, C7.1, J1.3, J1.4, J2.4
unnamed: C1.1, J2.2, J2.3, L1.2, L3.2
unnamed: C2.1, C3.1, C4.1, C5.2, L2.2
unnamed: C2.2, C3.2, L1.1
unnamed: C5.1, C6.1, J1.1, J1.2, L2.1
unnamed: C7.2, J2.1, L3.1

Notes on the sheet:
20 turns

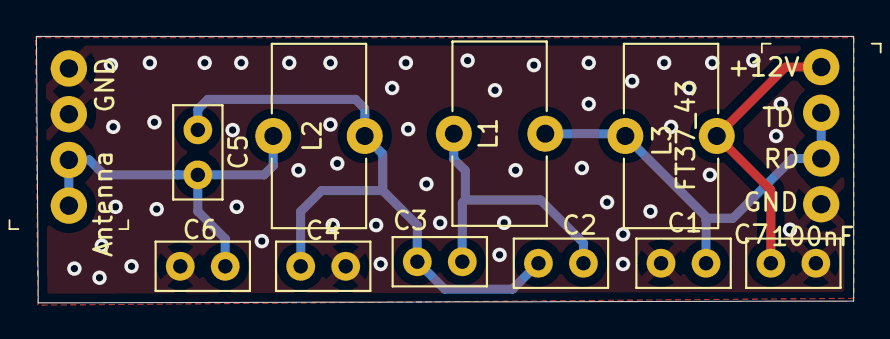
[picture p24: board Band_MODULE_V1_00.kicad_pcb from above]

Board: 2 copper layers, 45.4 x 14.8 mm, 12 parts (0 on the bottom side), 6 nets.

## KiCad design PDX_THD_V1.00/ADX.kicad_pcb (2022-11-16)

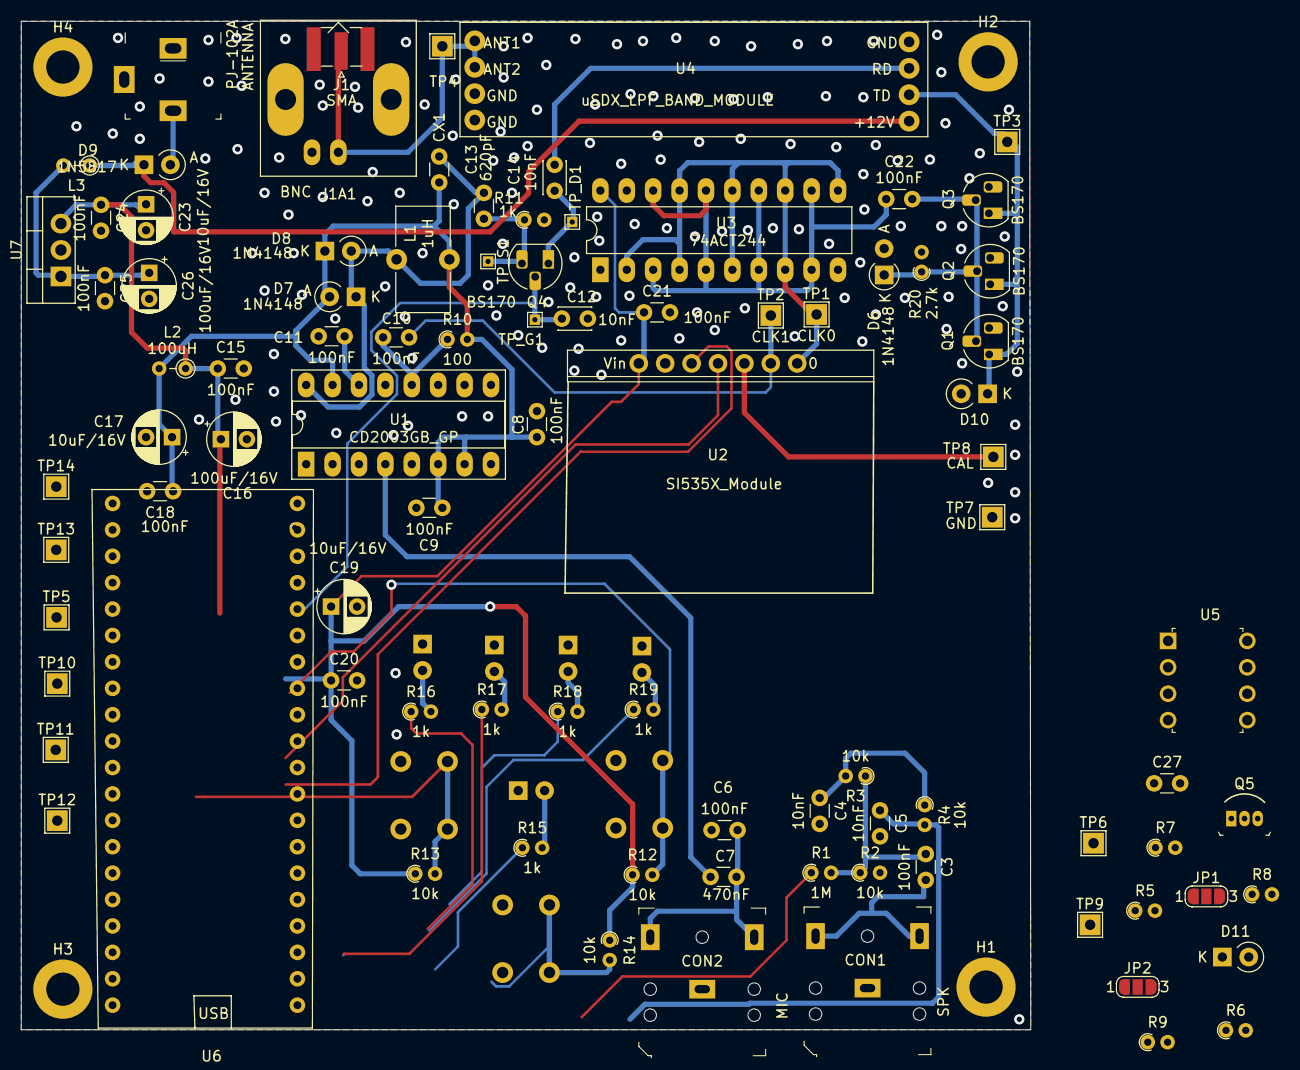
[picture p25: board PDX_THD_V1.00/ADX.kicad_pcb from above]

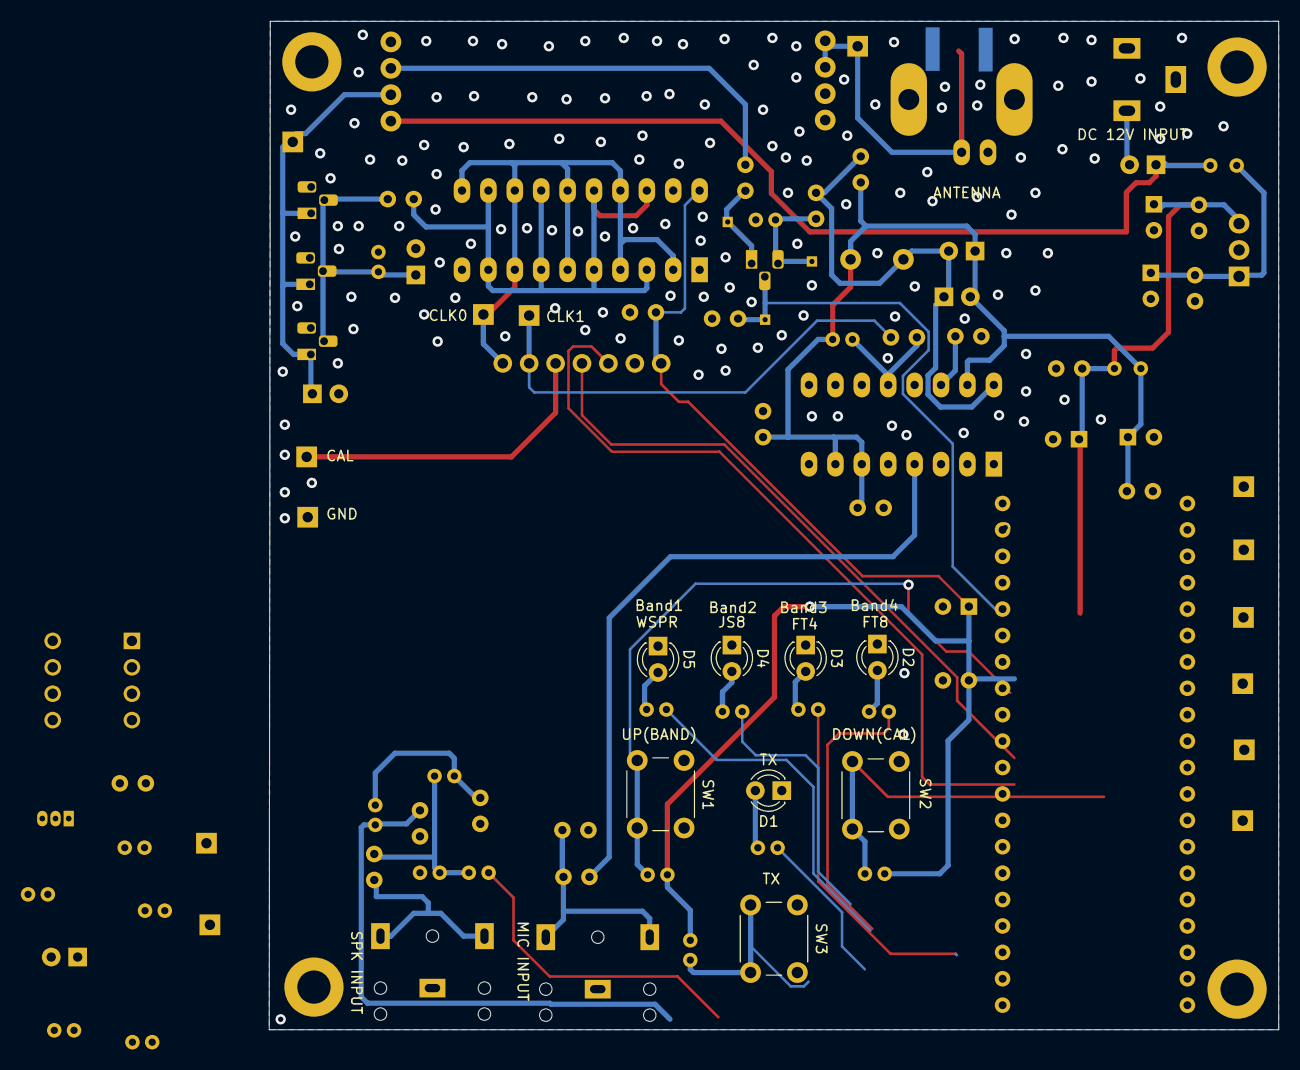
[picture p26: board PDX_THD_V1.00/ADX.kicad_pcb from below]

Board: 2 copper layers, 97.1 x 97.0 mm, 103 parts (8 on the bottom side), 53 nets.

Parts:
C3, C6, C8, C9, C10, C11, C15, C18, C20, C21, C22, C24, C25, C27: 100nF; C_Disc_D3.0mm_W1.6mm_P2.50mm
C4, C5: 10nF; C_Disc_D3.0mm_W1.6mm_P2.50mm
C7: 470nF; C_Disc_D3.0mm_W1.6mm_P2.50mm
C12, C14: 10nF; C_Disc_D3.0mm_W2.0mm_P2.50mm
C13: 620pF; C_Disc_D3.0mm_W1.6mm_P2.50mm
C16, C26: 100uF/16V; CP_Radial_D5.0mm_P2.50mm
C17, C19, C23: 10uF/16V; CP_Radial_D5.0mm_P2.50mm
CON1: SPK; Headphone_Jack_3.5mm_SJ1-3523N
CON2: MIC; Headphone_Jack_3.5mm_SJ1-3523N
CX1: C_Disc_D3.0mm_W1.6mm_P2.50mm
D1: TX; LED_D3.0mm
D2: FT8; LED_D3.0mm
D3: FT4; LED_D3.0mm
D4: JS8; LED_D3.0mm
D5: WSPR; LED_D3.0mm
D6: 1N4148; D_A-405_P2.54mm_Vertical_AnodeUp
D7, D8: 1N4148; D_A-405_P2.54mm_Vertical_KathodeUp
D9: 1N5817; D_A-405_P2.54mm_Vertical_KathodeUp
D10: 1N4756; D_A-405_P2.54mm_Vertical_KathodeUp
D11: 1N34; D_A-405_P2.54mm_Vertical_KathodeUp
H1, H2, H3, H4: MountingHole_Pad; MountingHole_3.2mm_M3_ISO7380_Pad
J1: SMA; SMA_Samtec_SMA-J-P-X-ST-EM1_EdgeMount
J1A1: BNC; BNC_Amphenol_B6252HB-NPP3G-50_Horizontal
J2: PJ-102A; Barrel_Jack_5.5mmODx2.1mmID_PJ-102A
JP1: T_O SLCT1; SolderJumper-3_P1.3mm_Open_RoundedPad1.0x1.5mm_NumberLabels
JP2: T_O SLCT2; SolderJumper-3_P1.3mm_Open_RoundedPad1.0x1.5mm_NumberLabels
L1: 1uH; L_Toroid_Vertical_L10.0mm_W5.0mm_P5.08mm
L2, L3: 100uH; R_Axial_DIN0204_L3.6mm_D1.6mm_P2.54mm_Vertical
Q1, Q2, Q3: BS170; TO-92_HandSolder
Q4: BS170; TO-92L_HandSolder
Q5: BS170; TO-92-3
R1: 1M; R_Axial_DIN0204_L3.6mm_D1.6mm_P1.90mm_Vertical
R2, R3, R4, R7, R12, R13, R14: 10k; R_Axial_DIN0204_L3.6mm_D1.6mm_P1.90mm_Vertical
R5, R6, R8, R11, R15, R16, R17, R18, R19: 1k; R_Axial_DIN0204_L3.6mm_D1.6mm_P1.90mm_Vertical
R9: 100k; R_Axial_DIN0204_L3.6mm_D1.6mm_P1.90mm_Vertical
R10: 100; R_Axial_DIN0204_L3.6mm_D1.6mm_P1.90mm_Vertical
R20: 2.7k; R_Axial_DIN0204_L3.6mm_D1.6mm_P1.90mm_Vertical
SW1: UP(BAND); SW_PUSH_6mm
SW2: DOWN(CAL); SW_PUSH_6mm
SW3: TX; SW_PUSH_6mm
TP1: CLK0; TestPoint_THTPad_2.0x2.0mm_Drill1.0mm
TP2: CLK1; TestPoint_THTPad_2.0x2.0mm_Drill1.0mm
TP3, TP4: TestPoint; TestPoint_THTPad_2.0x2.0mm_Drill1.0mm
TP5: ATU; TestPoint_THTPad_2.0x2.0mm_Drill1.0mm
TP6, TP12: CW; TestPoint_THTPad_2.0x2.0mm_Drill1.0mm
TP7: GND; TestPoint_THTPad_2.0x2.0mm_Drill1.0mm
TP8: CAL; TestPoint_THTPad_2.0x2.0mm_Drill1.0mm
TP9: AF; TestPoint_THTPad_2.0x2.0mm_Drill1.0mm
TP10: BT; TestPoint_THTPad_2.0x2.0mm_Drill1.0mm
TP11: CLK; TestPoint_THTPad_2.0x2.0mm_Drill1.0mm
TP13: UART_RX; TestPoint_THTPad_2.0x2.0mm_Drill1.0mm
TP14: UART_TX; TestPoint_THTPad_2.0x2.0mm_Drill1.0mm
TP_D1: TestPoint_THTPad_1.0x1.0mm_Drill0.5mm
TP_G1: TestPoint_THTPad_1.0x1.0mm_Drill0.5mm
TP_S1: TestPoint_THTPad_1.0x1.0mm_Drill0.5mm
U1: CD2003GB_GP; DIP-16_W7.62mm_Socket_LongPads
U2: SI535X_Module; SI5351 Module_Vertical
U3: 74ACT244; DIP-20_W7.62mm_LongPads
U4: uSDX_LPF_BAND_MODULE; uSDX_LPF_Band_Module
U5: LM393N_LTB; DIP-8_W7.62mm
U6: RP2040_PICO; RPI_PICO
U7: LM7805; TO-220-3_Vertical

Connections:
+3.3V: C27.2, R1.1, R7.1, R8.1, U5.8, U6.36
+5V: C15.1, C16.1, C19.1, C20.1, C21.1, C23.1, C24.1, L2.1, R12.1, R13.1, R14.1, U2.1, U3.20, U6.40, U7.3
CAL: TP8.1, U2.5, U6.12
FSK: JP2.2, U6.32
FT4LED: R17.1, U6.7
FT8LED: R16.1, U6.6
GNDPWR: C4.2, C5.2, C6.2, C8.1, C9.1, C11.1, C12.2, C15.2, C16.2, C17.2, C18.2, C19.2, C20.2, C21.2, C23.2, C24.2, C25.2, C26.2, C27.1, CON1.1, CON2.1, D1.1, D2.1, D3.1, D4.1, D5.1, D6.2, D10.2, D11.1, H1.1, H2.1, H3.1, H4.1, J1.2, J1A1.2, J2.2, Q1.3, Q2.3, Q3.3, Q5.3, R2.2, R9.2, R11.2, R20.2, SW1.1, SW2.1, SW3.1, TP7.1, U1.1, U1.2, U1.5, U1.9, U2.2, U3.1, U3.10, U3.19, U4.4, U4.7, U4.8, U5.3, U5.4, U6.3, U6.8, U6.13, U6.18, U6.23, U6.28, U6.33, U6.38, U7.2
JS8LED: R18.1, U6.9
unnamed: C3.1, R1.2, R2.1, R3.1
unnamed: C3.2, CON1.3, TP9.1
unnamed: C4.1, R3.2, R4.1
unnamed: C5.1, JP1.2, R4.2
unnamed: C6.1, C7.1, CON2.2, CON2.3
unnamed: C10.1, R10.1
unnamed: C11.2, U1.16
unnamed: C13.1, Q4.3, R11.1, TP_S1.1, U1.6, U1.7, U1.15
unnamed: C13.2, CX1.1, D7.1, D8.2, L1.1
unnamed: C14.1, Q4.1, TP_D1.1
unnamed: C8.2, C9.2, C17.1, C18.1, CX1.2, D7.2, D8.1, L1.2, L2.2, R10.2
unnamed: C22.1, D6.1, Q1.2, Q2.2, Q3.2, R20.1
unnamed: C22.2, U3.3, U3.5, U3.7, U3.9, U3.12, U3.14, U3.16, U3.18
unnamed: C25.1, C26.1, L3.2, U7.1
unnamed: CON1.2, TP6.1
unnamed: D1.2, R15.2
unnamed: D2.2, R16.2
unnamed: D3.2, R17.2
unnamed: D4.2, R18.2
unnamed: D5.2, R19.2
unnamed: D9.1, L3.1, U4.1
unnamed: D9.2, J2.1
unnamed: D11.2, R5.1, R6.2
unnamed: J1.1, J1A1.1, TP4.1, U4.5, U4.6
unnamed: JP1.1, R5.2
unnamed: JP1.3, Q5.2, R9.1
unnamed: JP2.1, Q5.1, R8.2
unnamed: JP2.3, R7.2, U5.1
unnamed: R6.1, U5.2
unnamed: TP1.1, U2.7, U3.2, U3.4, U3.6, U3.8, U3.11, U3.13, U3.15, U3.17
unnamed: TP5.1, U6.20
unnamed: TP13.1, U6.16
unnamed: TP14.1, U6.17
RX: C14.2, U4.3
RXA: C7.2, U1.4
RXSW: C12.1, Q4.2, TP_G1.1, U6.4
RX_OSC: C10.2, TP2.1, U2.6
SCL: U2.4, U6.22
SDA: U2.3, U6.21
SW1: R12.2, SW1.2, TP10.1, U6.14
SW2: R13.2, SW2.2, TP11.1, U6.15
SW3: R14.2, SW3.2, TP12.1, U6.11
TD_IN: D10.1, Q1.1, Q2.1, Q3.1, TP3.1, U4.2
TXLED: R15.1, U6.5
WSPRLED: R19.1, U6.10

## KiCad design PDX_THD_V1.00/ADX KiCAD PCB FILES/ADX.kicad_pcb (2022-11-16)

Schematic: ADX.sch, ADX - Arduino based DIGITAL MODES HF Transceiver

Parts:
C1, C16, C24: 100uF/16V; CP_Radial_D5.0mm_P2.50mm
C2, C3, C6, C8, C9, C10, C14, C15, C19, C20, C21, C22, C23: 100nF; C_Disc_D3.0mm_W1.6mm_P2.50mm
C4, C5: 10nF; C_Disc_D3.0mm_W1.6mm_P2.50mm
C7: 470nF; C_Disc_D3.0mm_W1.6mm_P2.50mm
C11: 620pF; C_Disc_D3.0mm_W1.6mm_P2.50mm
C12, C17: 10nF; C_Disc_D3.0mm_W2.0mm_P2.50mm
C13, C18: 10uF/16V; CP_Radial_D5.0mm_P2.50mm
CON1: SPK; Headphone_Jack_3.5mm_SJ1-3523N; MPN SJ1-3523N; Digi-Key_PN CP1-3523N-ND
CON2: MIC; Headphone_Jack_3.5mm_SJ1-3523N; MPN SJ1-3523N; Digi-Key_PN CP1-3523N-ND
CX1: C_Disc_D3.0mm_W1.6mm_P2.50mm
D1: TX; LED_D3.0mm
D2: FT8; LED_D3.0mm
D3: FT4; LED_D3.0mm
D4: JS8; LED_D3.0mm
D5: WSPR; LED_D3.0mm
D6: 1N4148; D_A-405_P2.54mm_Vertical_AnodeUp
D7, D8: 1N4148; D_A-405_P2.54mm_Vertical_KathodeUp
D9: 1N5817; D_A-405_P2.54mm_Vertical_KathodeUp
GND1: TestPoint_THTPad_2.0x2.0mm_Drill1.0mm
H1, H2, H3, H4: MountingHole_Pad; MountingHole_3.2mm_M3_ISO7380_Pad
J1: SMA; SMA_Samtec_SMA-J-P-X-ST-EM1_EdgeMount
J1A1: BNC; BNC_Amphenol_B6252HB-NPP3G-50_Horizontal
J2: PJ-102A; Barrel_Jack_5.5mmODx2.1mmID_PJ-102A; MPN PJ-102A; Digi-Key_PN CP-102A-ND
L1: 1uH; L_Toroid_Vertical_L10.0mm_W5.0mm_P5.08mm
L2: 100uH; R_Axial_DIN0204_L3.6mm_D1.6mm_P2.54mm_Vertical
Q1, Q2, Q3: BS170; TO-92_HandSolder; MPN BS170; Digi-Key_PN BS170-ND
Q4: BS170; TO-92L_HandSolder; MPN BS170; Digi-Key_PN BS170-ND
R1: 1M; R_Axial_DIN0204_L3.6mm_D1.6mm_P1.90mm_Vertical
R2: 4.7k; R_Axial_DIN0204_L3.6mm_D1.6mm_P1.90mm_Vertical
R3, R4, R10, R11, R15: 10k; R_Axial_DIN0204_L3.6mm_D1.6mm_P1.90mm_Vertical
R5, R6, R7, R8, R9, R13: 1k; R_Axial_DIN0204_L3.6mm_D1.6mm_P1.90mm_Vertical
R12: 2.7k; R_Axial_DIN0204_L3.6mm_D1.6mm_P1.90mm_Vertical
R14: 100; R_Axial_DIN0204_L3.6mm_D1.6mm_P1.90mm_Vertical
SW1: UP(BAND); SW_PUSH_6mm
SW2: DOWN(CAL); SW_PUSH_6mm
SW3: TX; SW_PUSH_6mm
TP1: CLK0; TestPoint_THTPad_2.0x2.0mm_Drill1.0mm
TP2: CLK1; TestPoint_THTPad_2.0x2.0mm_Drill1.0mm
TP3, TP4: TestPoint; TestPoint_THTPad_2.0x2.0mm_Drill1.0mm
TP7: GND; TestPoint_THTPad_2.0x2.0mm_Drill1.0mm
TP8: CAL; TestPoint_THTPad_2.0x2.0mm_Drill1.0mm
TP_D1: TestPoint_THTPad_1.0x1.0mm_Drill0.5mm
TP_G1: TestPoint_THTPad_1.0x1.0mm_Drill0.5mm
TP_S1: TestPoint_THTPad_1.0x1.0mm_Drill0.5mm
U1: CD2003GB_GP; DIP-16_W7.62mm_Socket_LongPads
U2: SI535X_Module; SI5351 Module_Vertical
U3: 74ACT244; DIP-20_W7.62mm_LongPads
U4: uSDX_LPF_BAND_MODULE; uSDX_LPF_Band_Module
XA1: Arduino_Nano_Socket

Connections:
+3.3V: R1.1, XA1.3V3 (3.3V)
+5V: C1.1, C2.1, C15.1, C16.1, C23.1, L2.1, R10.1, R11.1, R15.1, U2.1 (VIN), U3.20 (VCC), XA1.5V
+12V: C18.1, C19.1, C20.1, C24.1, D9.1 (K), U4.1 (+12V), XA1.VIN
FSK: C5.1, R4.2, XA1.D7
GNDPWR: C1.2, C2.2, C4.2, C5.2, C6.2, C8.1, C9.1, C10.1, C12.2, C13.2, C14.2, C15.2, C16.2, C18.2, C19.2, C20.2, C23.2, C24.2, CON1.1 (S), CON2.1 (S), D1.1 (K), D2.1 (K), D3.1 (K), D4.1 (K), D5.1 (K), D6.2 (A), GND1.1, H1.1, H2.1, H3.1, H4.1, J1.2 (Ext), J1A1.2 (Ext), J2.2, Q1.3 (S), Q2.3 (S), Q3.3 (S), R2.2, R12.2, R13.2, SW1.1, SW2.1, SW3.1, TP7.1, U1.1, U1.2, U1.5, U1.9, U2.2 (GND), U3.1 (OEa), U3.10 (GND), U3.19 (OEb), U4.4 (GND), U4.7 (GND), U4.8 (GND), XA1.D6, XA1.GND1 (GND), XA1.GND2 (GND)
unnamed: C3.1, R1.2, R2.1, R3.1
unnamed: C3.2, CON1.2 (T), CON1.3 (R)
unnamed: C4.1, R3.2, R4.1
unnamed: C6.1, C7.1, CON2.2 (T), CON2.3 (R)
unnamed: C10.2, U1.14
unnamed: C11.1, Q4.3 (S), R13.1, TP_S1.1
unnamed: C11.2, CX1.1, D7.1 (K), D8.2 (A), L1.1, U1.16
unnamed: C8.2, C9.2, C13.1, C14.1, CX1.2, D7.2 (A), D8.1 (K), L1.2, L2.2, R14.2, U1.6, U1.7, U1.15
unnamed: C17.1, Q4.1 (D), TP_D1.1
unnamed: C21.1, R14.1, U1.12
unnamed: C22.1, D6.1 (K), Q1.2 (G), Q2.2 (G), Q3.2 (G), R12.1
unnamed: C22.2, U3.3 (O3b), U3.5 (O2b), U3.7 (O1b), U3.9 (O0b), U3.12 (O3a), U3.14 (O2a), U3.16 (O1a), U3.18 (O0a)
unnamed: D1.2 (A), R5.2
unnamed: D2.2 (A), R6.2
unnamed: D3.2 (A), R7.2
unnamed: D4.2 (A), R8.2
unnamed: D5.2 (A), R9.2
unnamed: D9.2 (A), J2.1
unnamed: J1.1 (In), J1A1.1 (In), TP4.1, U4.5 (ANT1), U4.6 (ANT2)
unnamed: R5.1, XA1.D13 (D13_SCK)
unnamed: R6.1, XA1.D12 (D12_MISO)
unnamed: R7.1, XA1.D11 (D11_MOSI)
unnamed: R8.1, XA1.D10 (D10_CS)
unnamed: R9.1, XA1.D9
unnamed: TP1.1, U2.7 (SO), U3.2 (I0a), U3.4 (I1a), U3.6 (I2a), U3.8 (I3a), U3.11 (I0b), U3.13 (I1b), U3.15 (I2b), U3.17 (I3b)
unnamed: TP8.1, U2.5 (S2)
RX: C17.2, U4.3 (RD)
RXA: C7.2, U1.4
RXSW: C12.1, Q4.2 (G), TP_G1.1, XA1.D8
RX_OSC: C21.2, TP2.1, U2.6 (S1)
SCL: U2.4 (SCL), XA1.A5 (A5_SCL)
SDA: U2.3 (SDA), XA1.A4 (A4_SDA)
SW1: R10.2, SW1.2, XA1.D2 (D2_INT0)
SW2: R11.2, SW2.2, XA1.D3 (D3_INT1)
SW3: R15.2, SW3.2, XA1.D4
TD_IN: Q1.1 (D), Q2.1 (D), Q3.1 (D), TP3.1, U4.2 (TD)

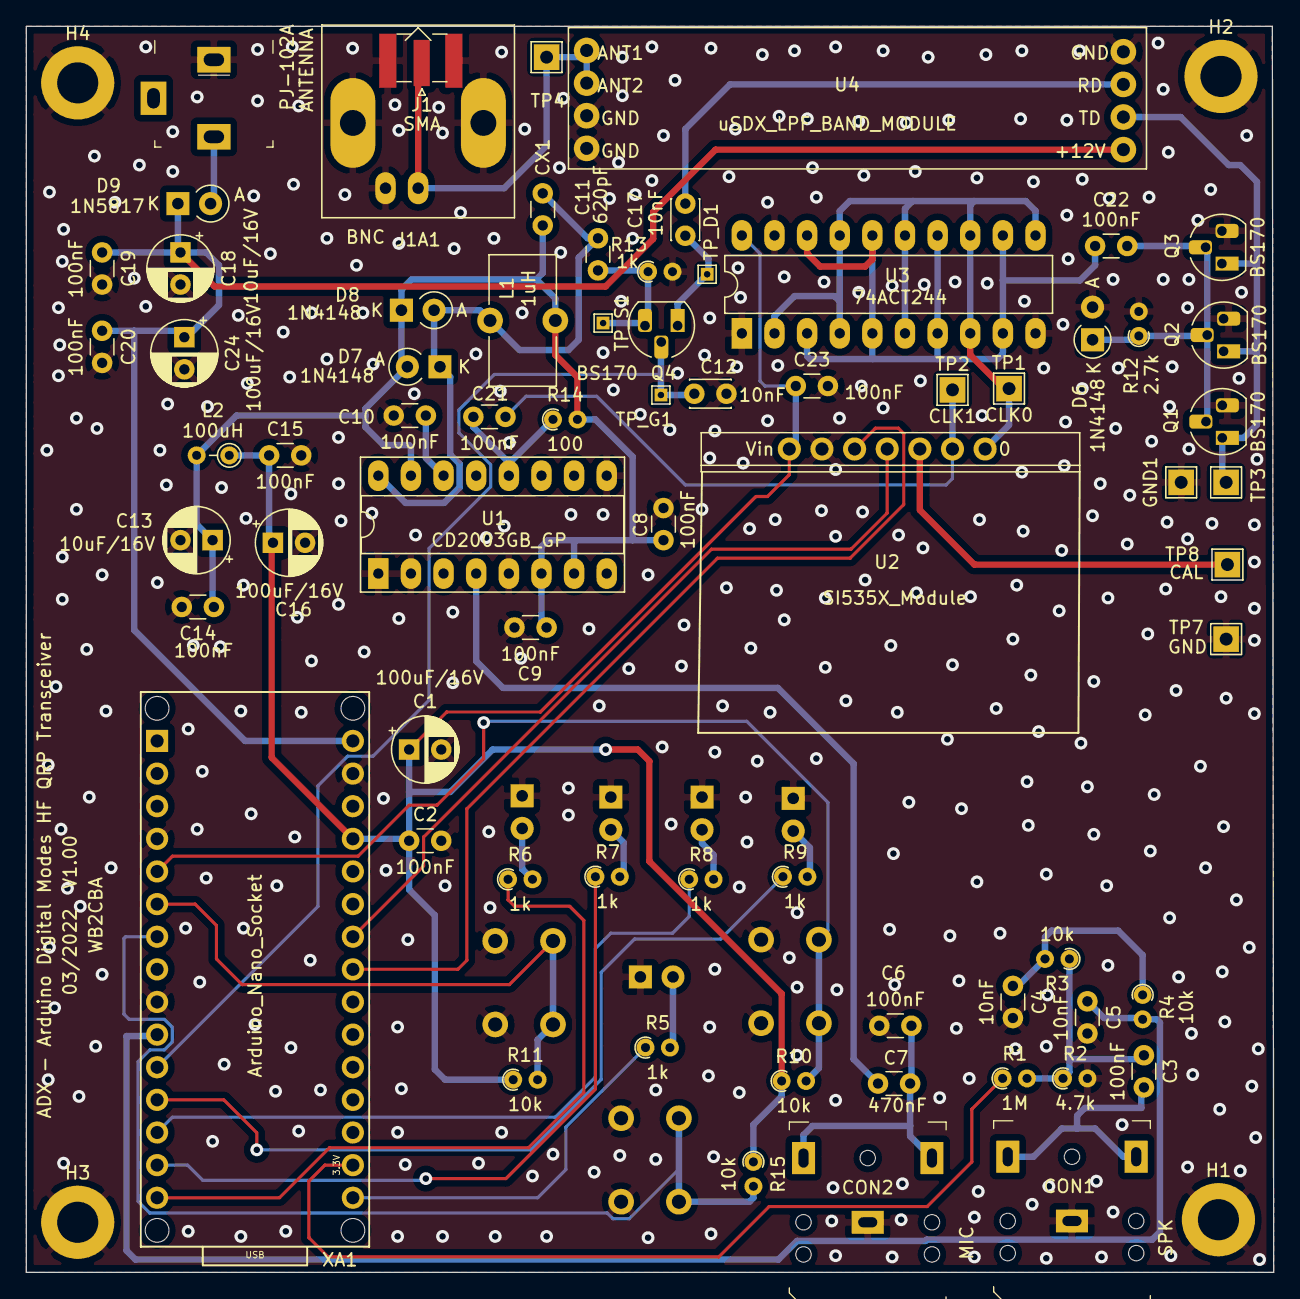
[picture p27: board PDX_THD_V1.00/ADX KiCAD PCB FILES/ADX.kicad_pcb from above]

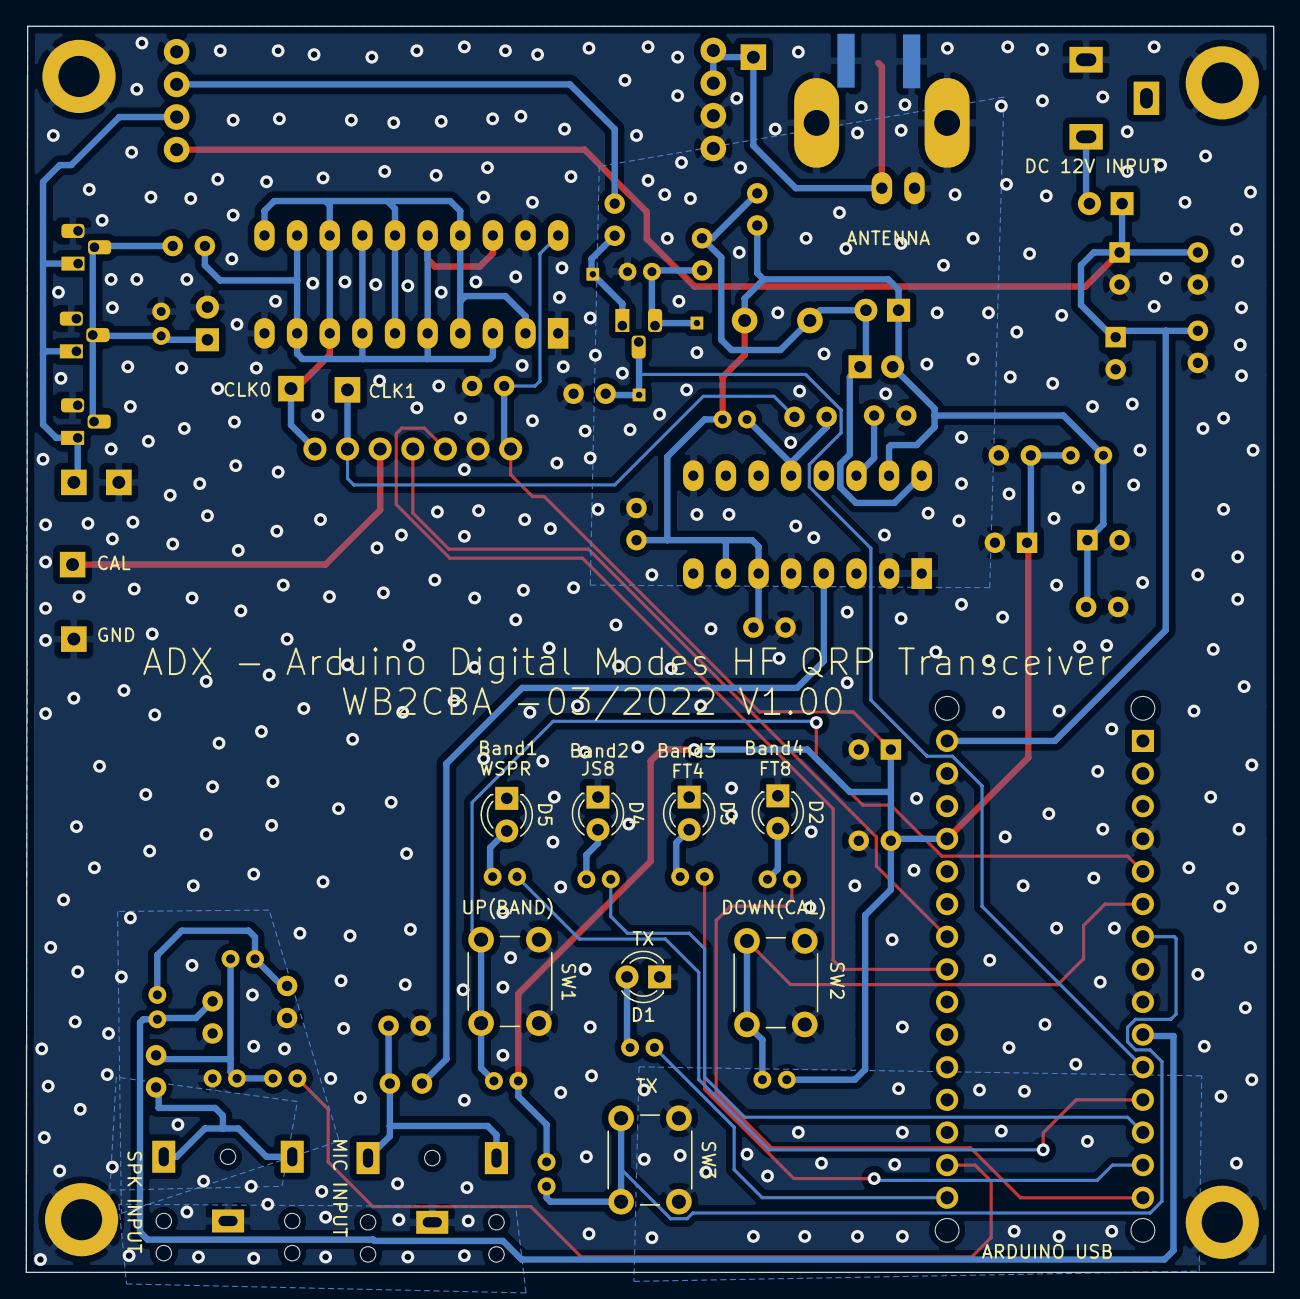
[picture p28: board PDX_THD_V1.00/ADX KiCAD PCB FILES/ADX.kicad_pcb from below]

Board: 2 copper layers, 97.1 x 97.0 mm, 82 parts (8 on the bottom side), 41 nets.

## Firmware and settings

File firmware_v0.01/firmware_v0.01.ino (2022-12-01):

#include <si5351.h>
#include "Wire.h"
#include <EEPROM.h>

#include "pdx_common.h"

Si5351 si5351;

// Variables
int pwm_slice;
double fsequences[NFS];
uint32_t ffsk     = 0;
uint32_t f_hi;
uint32_t fclk     = 0;
int32_t  error    = 0;
uint32_t codefreq = 0;
int nfsi   = 0;
uint32_t prevfreq = 0;
double pfo;
unsigned long freq = 14074000; // Start on the "DX band (20m)" by default
int32_t cal_factor = 0; // Sorted out by auto-calibration algorithm
int core1_initialization_partially_done = 0;
int core2_initialization_partially_done = 0;
extern char inTx;

// Debug helper
void led_flash()
{
  digitalWrite(LED_BUILTIN, HIGH);
  delay(250);
  digitalWrite(LED_BUILTIN, LOW);
  delay(250);
  digitalWrite(LED_BUILTIN, HIGH);
  delay(250);
  digitalWrite(LED_BUILTIN, LOW);
  delay(250);
  digitalWrite(LED_BUILTIN, HIGH);
  delay(250);
  digitalWrite(LED_BUILTIN, LOW);
  delay(250);
  digitalWrite(LED_BUILTIN, HIGH);
  delay(250);
  digitalWrite(LED_BUILTIN, LOW);
}

void setup()
{
  int ret;

  // Pins
  pinMode(RX, OUTPUT);
  pinMode(LED_BUILTIN, OUTPUT);
  pinMode(CAL, INPUT);

  Serial.begin(115200);

  Serial1.setTX(12);
  Serial1.setRX(13);
  Serial1.begin(115200);

  // I2C pins
  Wire.setSDA(16);
  Wire.setSCL(17);
  Wire.begin();

  // Initialize the Si5351
  ret = si5351.init(SI5351_CRYSTAL_LOAD_8PF, 0, cal_factor);
  if (ret != true) {
    led_flash();
    watchdog_reboot(0, 0, 1000);
  }
  si5351.output_enable(SI5351_CLK0, 0); // Turn of TX first - safety!

  core1_initialization_partially_done = 1; // Allow setup1() to run

  while (core2_initialization_partially_done == 0)
    delay(10);

  // Turn on RX
  digitalWrite(RX, 1);
  EEPROM.get(4, cal_factor);
  si5351.set_correction(cal_factor, SI5351_PLL_INPUT_XO);
  si5351.drive_strength(SI5351_CLK1, SI5351_DRIVE_2MA); // Set for reduced power for RX
  si5351.set_freq(freq * 100ULL, SI5351_CLK1);
  si5351.output_enable(SI5351_CLK1, 1);
}

void loop()
{
  int index;
  double fo;

  serialEvent(); // Listen for CAT control events

  if (rp2040.fifo.available() != 0 && inTx) {
    index = rp2040.fifo.pop();
    fo = fsequences[index];
    codefreq = fo;
    if (pfo != fo) {
      si5351.set_freq(((freq + fo) * 100ULL), SI5351_CLK0);
    }
  } else if (rp2040.fifo.available() != 0) {
    rp2040.fifo.pop(); // clear 'false' tx data
  }
}

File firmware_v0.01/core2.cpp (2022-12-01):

#include <Arduino.h>
#include "pdx_common.h"

// Automatic calibration
uint32_t f_hi_;

void pwm_int_() {
  pwm_clear_irq(7);
  f_hi_++;
}

void do_calibration()
{
  gpio_set_function(CAL, GPIO_FUNC_PWM);

  // Set CLK0 output for calibration
  si5351.drive_strength(SI5351_CLK2, SI5351_DRIVE_2MA); // Set for minimum power as we have an external amplifier
  si5351.set_freq(10000000 * 100ULL, SI5351_CLK2); // used for calibration
  si5351.output_enable(SI5351_CLK2, 1);

  // Warmup
  Serial1.println("Warming up for 7 seconds...");
  Serial1.println("Warming up for 7 seconds...");
  Serial1.println("Warming up for 7 seconds...");
  Serial1.println("Warming up for 7 seconds...");
  Serial1.println("Warming up for 7 seconds...");
  Serial1.println("Warming up for 7 seconds...");
  delay(7000);

  // Frequency counter
  int64_t existing_error = 0;
  int64_t error = 0;
  int count = 3; // reverse count
  uint64_t target_freq = 1000000000ULL; // 10 MHz, in hundredths of hertz
  uint32_t f = 0;
  while (true) {
    count = count - 1;
    pwm_config cfg = pwm_get_default_config();
    pwm_config_set_clkdiv_mode(&cfg, PWM_DIV_B_RISING);
    pwm_init(7, &cfg, false);
    gpio_set_function(CAL, GPIO_FUNC_PWM);
    irq_set_exclusive_handler(PWM_IRQ_WRAP, pwm_int_);
    pwm_set_irq_enabled(7, true);
    irq_set_enabled(PWM_IRQ_WRAP, true);
    f_hi_ = 0;
    si5351.set_correction(0, SI5351_PLL_INPUT_XO); // important - reset calibration
    uint32_t t = time_us_32() + 2;
    while (t > time_us_32());
    pwm_set_enabled(7, true);
    t += 3000000; // Gate time (in uSeconds), 3 seconds
    // t += 100000; // Gate time (in uSeconds), 100 ms
    while (t > time_us_32());
    pwm_set_enabled(7, false);
    f = pwm_get_counter(7);
    f += f_hi_ << 16;
    Serial1.print(f / 3.0); // Divide by gate time in seconds
    Serial1.println(" Hz");
    error = ((f / 3.0) * 100ULL) - target_freq;
    Serial1.print("Current calibration correction value is ");
    Serial1.printf("%" PRId64 "\n", error);
    Serial1.print("Total calibration value is ");
    Serial1.println(error + existing_error);
    if (count <= 0) { // Auto-calibration logic
      Serial1.println();
      Serial1.print(F("Calibration value is "));
      Serial1.println(error);
      Serial1.println(F("Setting calibration value automatically"));
      si5351.set_correction(error + existing_error, SI5351_PLL_INPUT_XO);
      existing_error = existing_error + error;
      si5351.set_pll(SI5351_PLL_FIXED, SI5351_PLLA);
      Serial1.println(F("Resetting target frequency"));
      si5351.set_freq(target_freq, SI5351_CLK0);
      // count = 3;
      break;
    }
  }

  // Save to EEPROM
  uint32_t magic = 0x1CEB00DA;
  EEPROM.put(0, magic);
  EEPROM.put(4, (uint32_t)existing_error);
  EEPROM.commit();
  delay(7000);
  // Serial1.printf("Saving calibration factor (%d) to EEPROM\n", existing_error);
}

uint32_t base_frequency = 700; // TODO: Avoid hardcoding this

// Interrupt IRQ for edge counting overflow
void pwm_int() {
  pwm_clear_irq(pwm_slice);
  f_hi++;
}

void setup1() {
  uint32_t magic;

  while (core1_initialization_partially_done == 0)
    delay(10);

  // Check for existing calibration
  EEPROM.begin(512);
  EEPROM.get(0, magic);
  if (magic != 0x1CEB00DA) {
    do_calibration();
    led_flash();
    watchdog_reboot(0, 0, 1000);
  }

  core2_initialization_partially_done = 1;

  /*
     ZCD algorithm
     defined by FSK_ZCD
     this is based on a pseudo cross detect
     where the rising edge is taken as a
     false cross detection followed by next
     edge which is also a false zcd but
     at the same level thus measuring the
     time between both will yield a period
     measurement proportional to the real
     period of the signal as measured
     two sucessive rising edges
     Measurements are made every 1 mSec
  */
  pwm_slice = pwm_gpio_to_slice_num(FSK);

  while (true) {
    pwm_config cfg = pwm_get_default_config();
    pwm_config_set_clkdiv_mode(&cfg, PWM_DIV_B_RISING);
    pwm_init(pwm_slice, &cfg, false);
    gpio_set_function(FSK, GPIO_FUNC_PWM);
    pwm_set_irq_enabled(pwm_slice, true);
    irq_set_exclusive_handler(PWM_IRQ_WRAP, pwm_int);
    irq_set_enabled(PWM_IRQ_WRAP, true);
    f_hi = 0;

    uint32_t t = time_us_32() + 2;                     // Allow all the settings to stabilize
    while (t > time_us_32());                          //
    uint32_t pwm_cnt = pwm_get_counter(pwm_slice);     // Get current pwm count
    pwm_set_enabled(pwm_slice, true);                  // enable pwm count
    while (pwm_get_counter(pwm_slice) == pwm_cnt) {}   // Wait till the count change
    pwm_cnt = pwm_get_counter(pwm_slice);              // Measure that value
    uint32_t t1 = time_us_32();                        // Mark first tick (t1)
    while (pwm_get_counter(pwm_slice) == pwm_cnt) {}   // Wait till the count change (a rise edge)
    uint32_t t2 = time_us_32();                        // Mark the second tick (t2)
    pwm_set_enabled(pwm_slice, false);                 // Disable counting
    if (t2 != t1) {                                    // Prevent noise to trigger a nul measurement
      float f = double(FSK_USEC) / (t2 - t1);          // Ticks are expressed in uSecs so convert to Hz
      f = f;                                           // Round to the nearest integer
      ffsk = uint32_t(f);                              // Convert to long integer for actual usage
      // TODO: Relax this - make it flexible / smarter
      if (ffsk >= base_frequency && ffsk <= base_frequency + 50) { // Only yield a value if within the baseband
        fsequences[nfsi] = f;
        rp2040.fifo.push_nb(nfsi);                     // Use the rp2040 FIFO IPC to communicate the new frequency
        nfsi = (nfsi + 1) % NFS;                       //
      }                                                //
    }                                                  //
    t = time_us_32() + FSK_SAMPLE;                     // Now wait for 1 mSec till next sample
    while (t > time_us_32()) ;
  }
}
